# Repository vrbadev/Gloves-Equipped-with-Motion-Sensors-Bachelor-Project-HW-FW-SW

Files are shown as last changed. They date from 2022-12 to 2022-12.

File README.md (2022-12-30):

# Gloves Equipped with Motion Sensors (HW & FW & SW)
 This project was created as a part of my bachelor thesis at the Czech Technical University. It contains complete hardware, firmware and software designs for smart Bluetooth gloves equipped with 15 6-DOF IMU sensors.

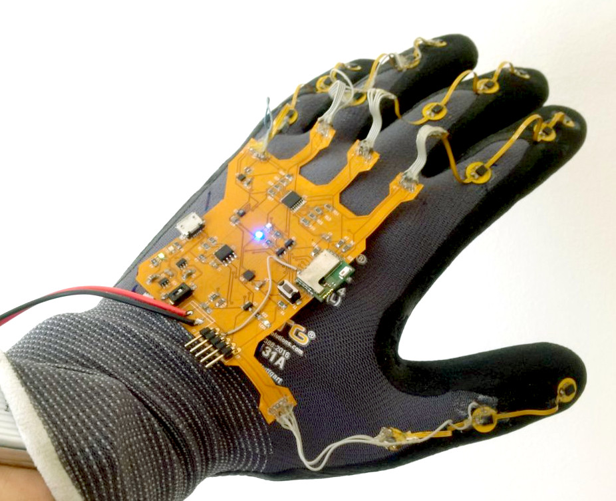
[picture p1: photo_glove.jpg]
Photo of the assembled glove


## About the Bachelor Thesis (Abstract)

This bachelor thesis focuses on the development of gloves equipped with motion sensors. The result of this work is supposed to be a functional device including 3D visualisation of measured bending of all fingers, so hand gestures can be determined. First of all, the theory of Bluetooth Low Energy devices is presented.The next chapter contains an explanation of hardware design details. Then the software implementation for the programmable BLE module is presented. Explanation of the theory of quaternion representation of the rotation and orientation in space for Madgwick's AHRS algorithm can be also found in this work. Python language has been chosen for implementing the visualisation. The thesis is completed with achieved results and ideas for further development.

Full text (in Czech language) is available at: https://dspace.cvut.cz/handle/10467/87657?locale-attribute=en

## Repository Contents

* **Hardware folder** - Contains complete Autodesk EAGLE projects for all related PCBs, including PDF schematics and layout visualisations.
* **Gerber folder** - Contains GERBER production archives for all of the designed PCBs.
* **Firmware folder** - Contains complete Keil uVision project with the firmware for the STMicroelectronics BlueNRG-M2SA Bluetooth module.
* **Software folder** - Contains Python software used for processing of the IMU data and for the visualisation.

## 3D Visualisation Software

A screenshot of the Python visualiser and the static code analysis are shown below.

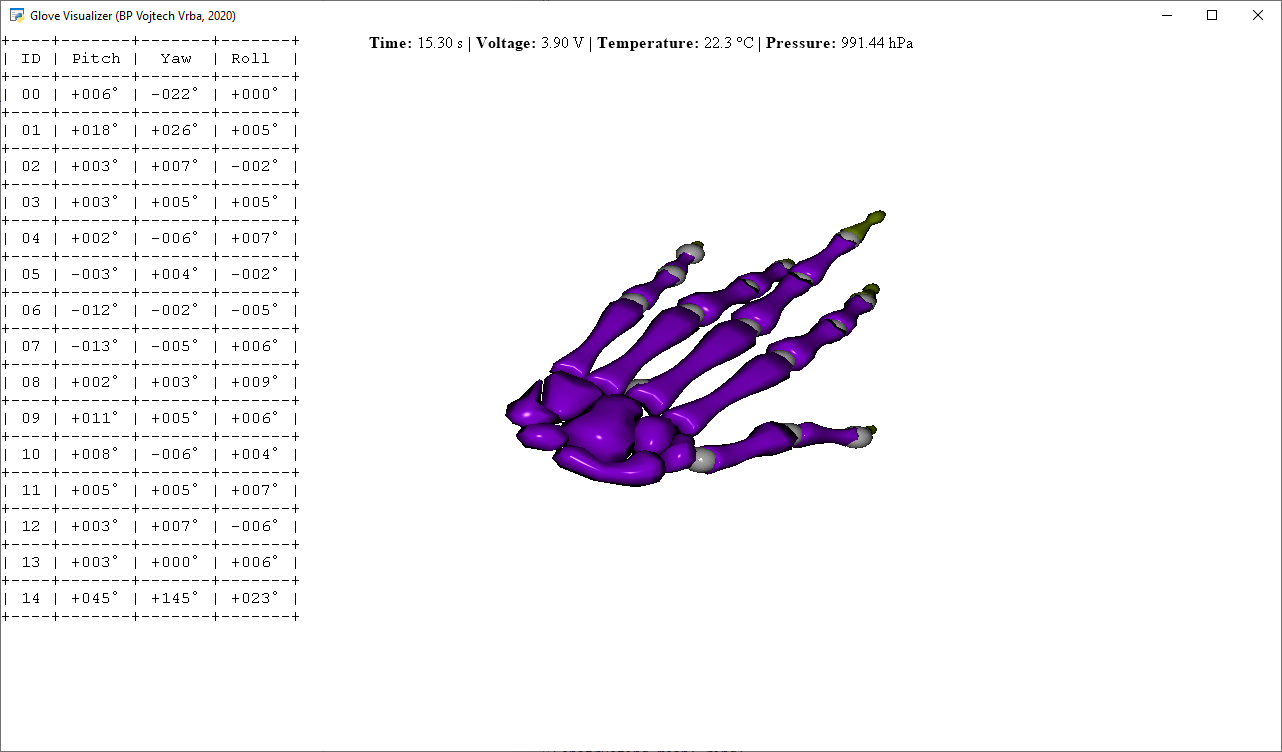
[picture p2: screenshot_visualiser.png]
Screenshot of the visualisation


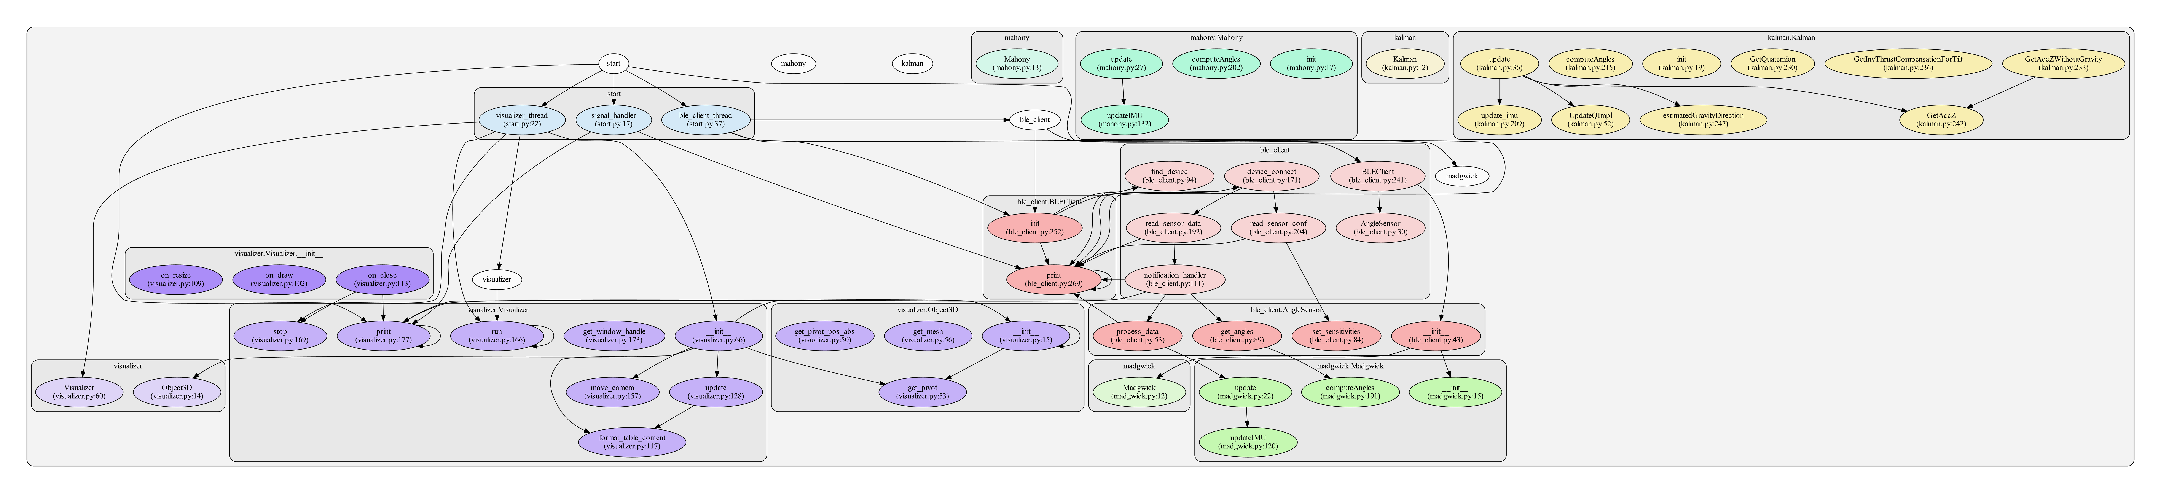
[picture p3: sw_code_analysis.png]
Static code analysis


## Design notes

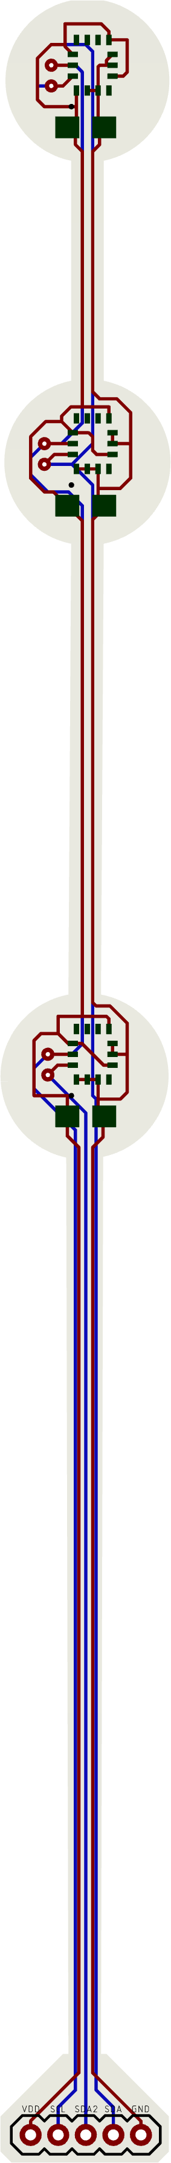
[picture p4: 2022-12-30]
Hardware/layout-little-finger.png

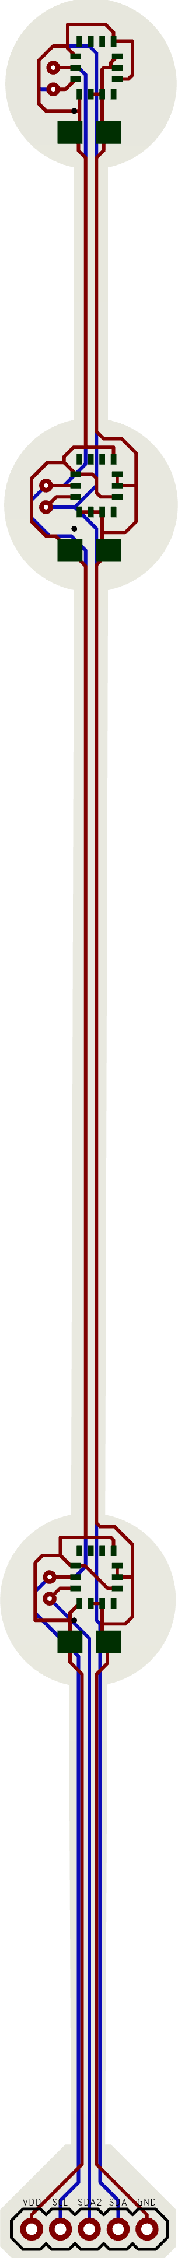
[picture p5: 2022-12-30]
Hardware/layout-index-finger.png

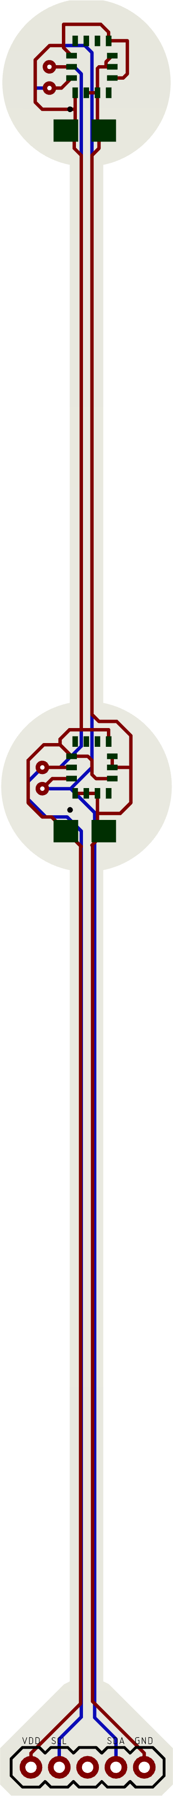
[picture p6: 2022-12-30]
Hardware/layout-thumb.png

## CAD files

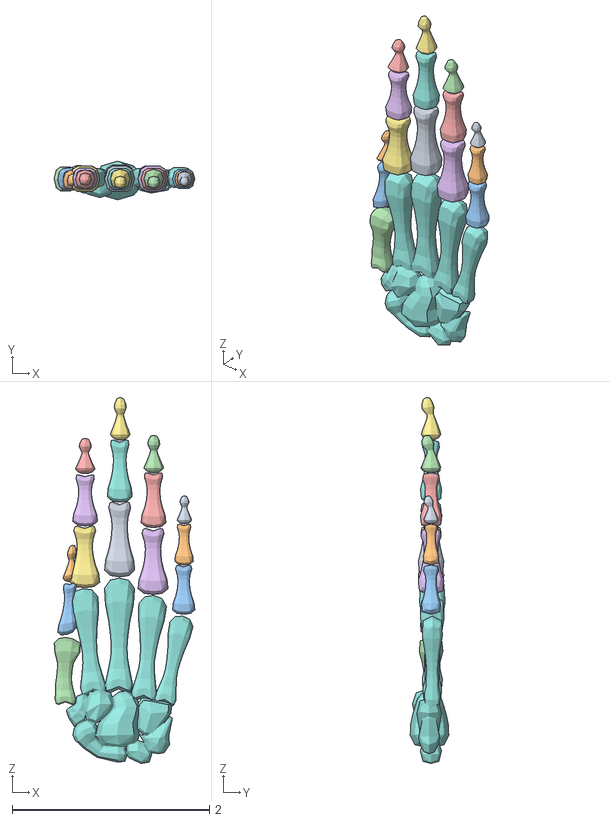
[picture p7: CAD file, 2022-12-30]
Software/Python/hand.obj
1.43 x 0.392 x 3.71
little3
little2
little1
ring3
ring2
ring1
middle3
middle2
middle1
thumb3
thumb2
thumb1
index3
index2
index1
hand

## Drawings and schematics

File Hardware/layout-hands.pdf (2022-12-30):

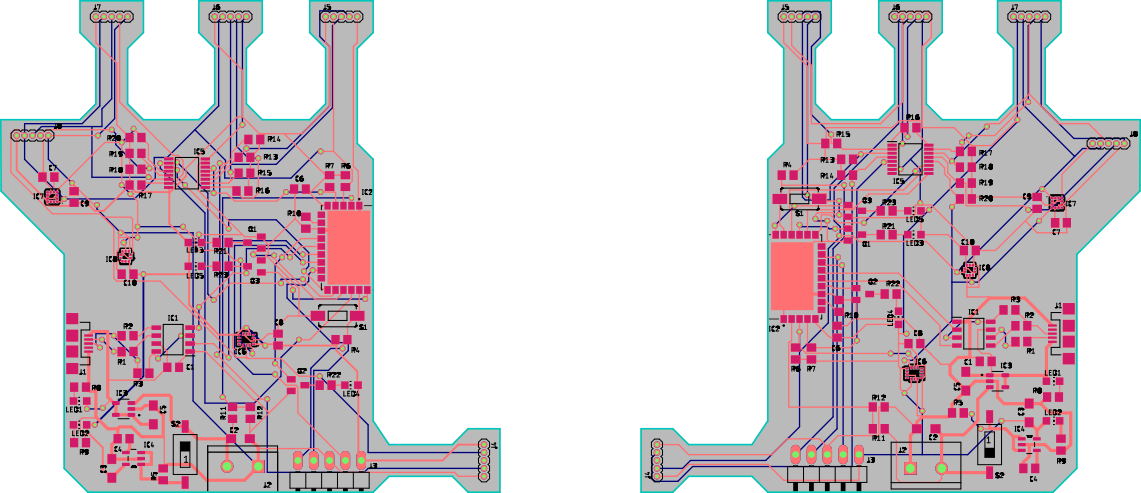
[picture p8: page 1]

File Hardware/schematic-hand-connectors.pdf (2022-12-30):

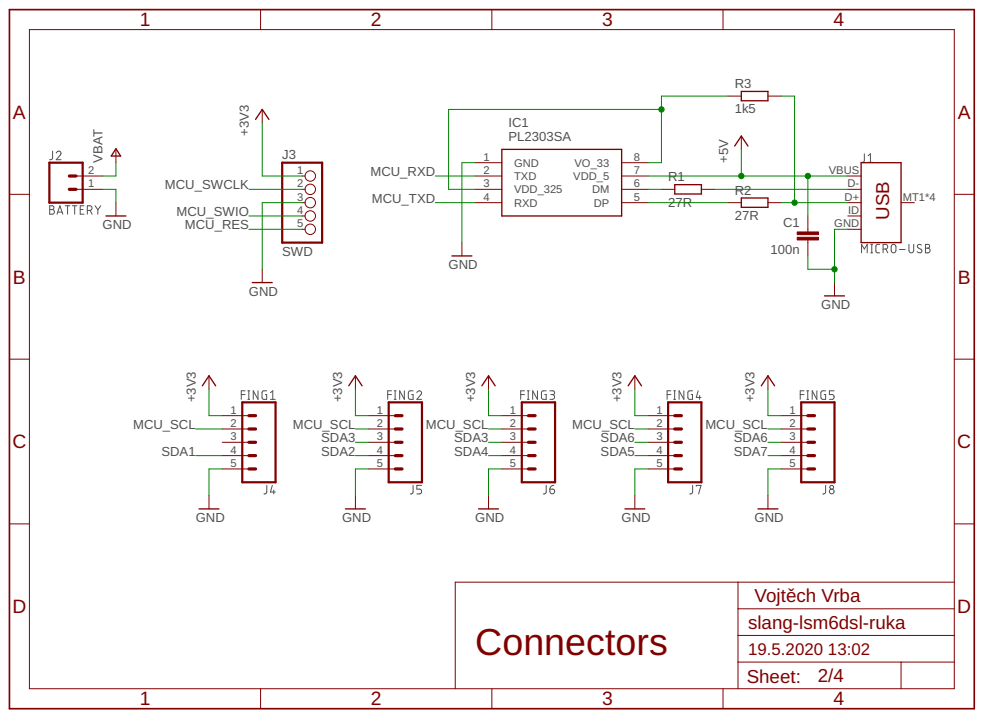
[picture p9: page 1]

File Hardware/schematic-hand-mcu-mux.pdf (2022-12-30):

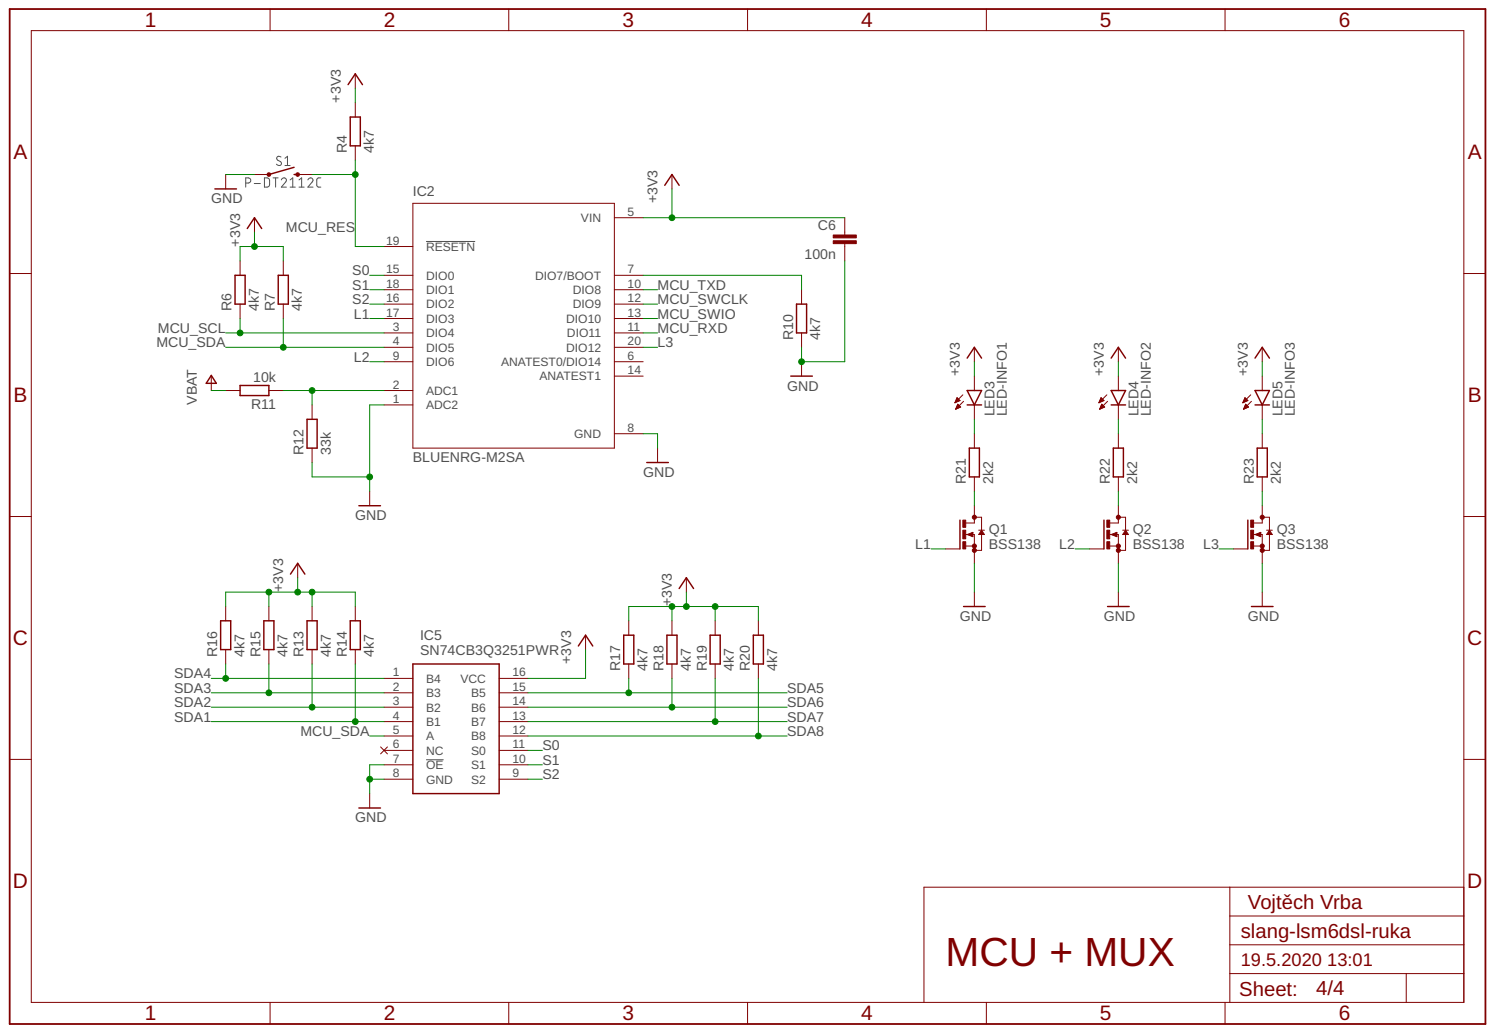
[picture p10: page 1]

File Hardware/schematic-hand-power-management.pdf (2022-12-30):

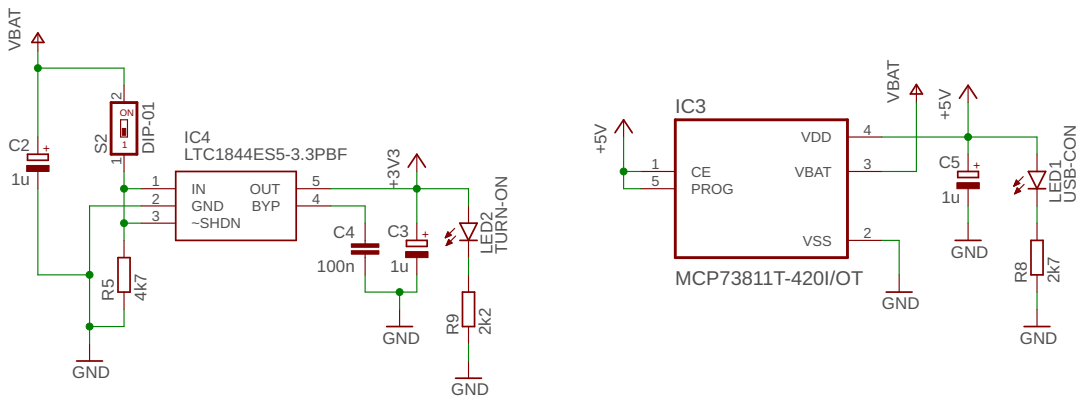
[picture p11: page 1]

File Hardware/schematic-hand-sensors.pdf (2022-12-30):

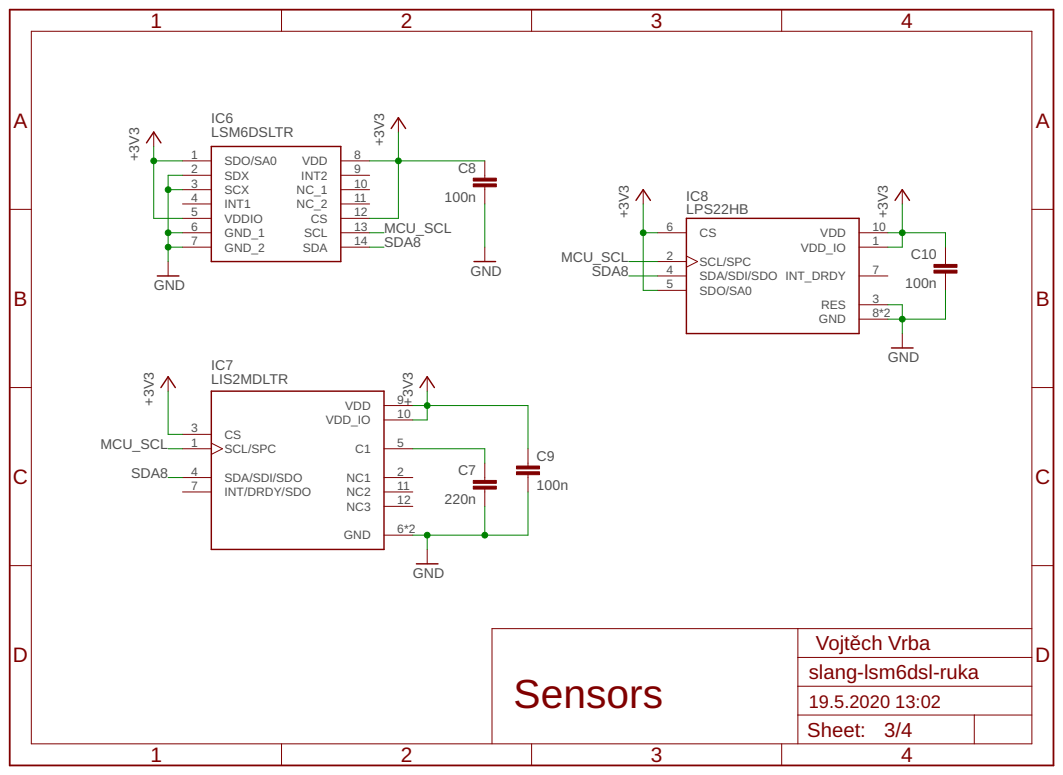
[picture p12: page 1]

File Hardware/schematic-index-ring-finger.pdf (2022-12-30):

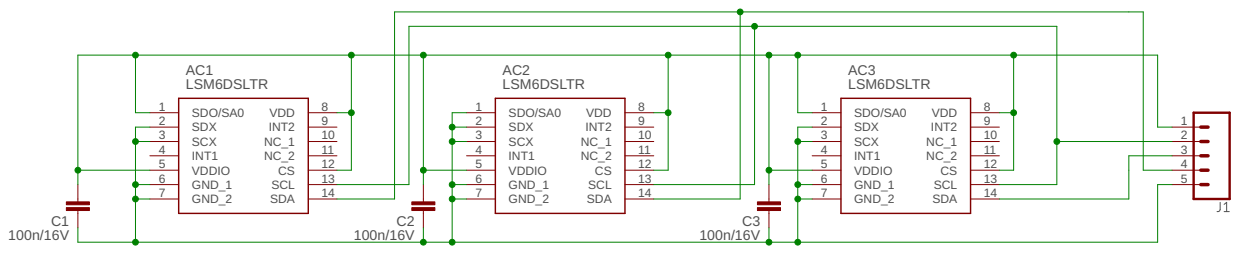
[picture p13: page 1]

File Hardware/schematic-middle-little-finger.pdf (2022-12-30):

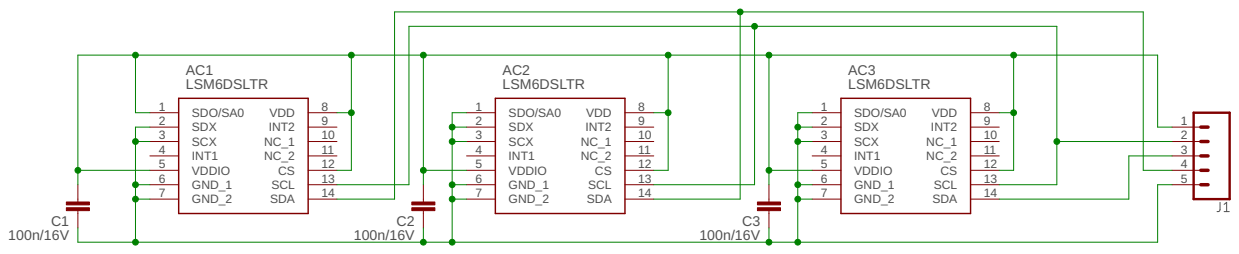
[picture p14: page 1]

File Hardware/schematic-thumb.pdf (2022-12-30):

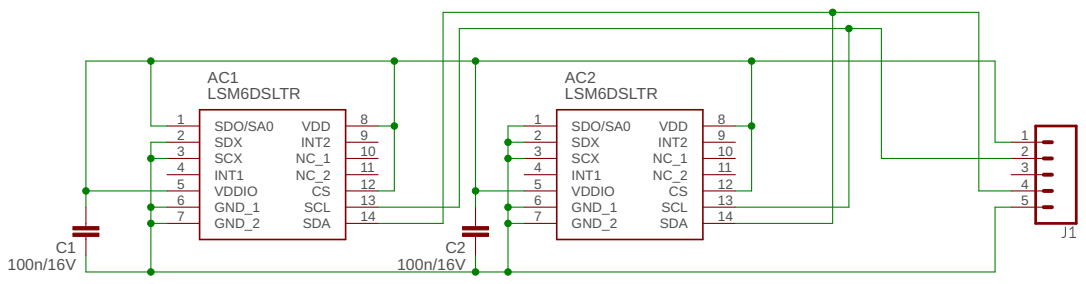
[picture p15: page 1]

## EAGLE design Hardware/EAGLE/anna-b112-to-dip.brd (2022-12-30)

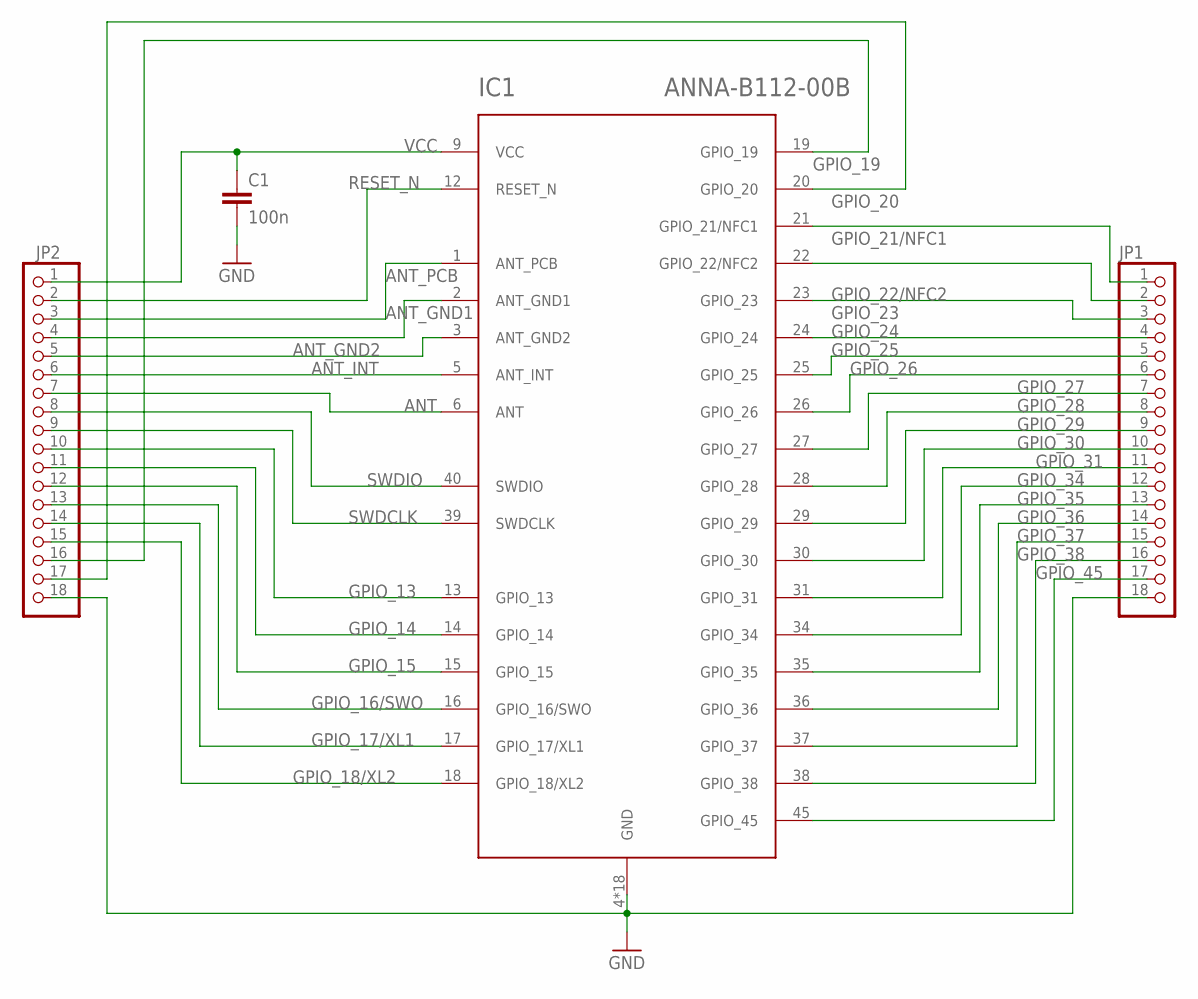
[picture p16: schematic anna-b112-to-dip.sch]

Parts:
C1: 100n; C0805
IC1: ANNA-B112-00B; ANNA-B112
JP1, JP2: PINHD-1X18; 1X18

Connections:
ANT: IC1.6 (ANT), JP2.7
ANT_GND1: IC1.2 (ANT_GND1), JP2.4
ANT_GND2: IC1.3 (ANT_GND2), JP2.5
ANT_INT: IC1.5 (ANT_INT), JP2.6
ANT_PCB: IC1.1 (ANT_PCB), JP2.3
GND: C1.2, IC1.4 (GND), IC1.7 (GND), IC1.8 (GND), IC1.10 (GND), IC1.11 (GND), IC1.32 (GND), IC1.33 (GND), IC1.41 (GND), IC1.42 (GND), IC1.43 (GND), IC1.44 (GND), IC1.46 (GND), IC1.47 (GND), IC1.48 (GND), IC1.49 (GND), IC1.50 (GND), IC1.51 (GND), IC1.52 (GND), JP1.18, JP2.18
GPIO_13: IC1.13 (GPIO_13), JP2.10
GPIO_14: IC1.14 (GPIO_14), JP2.11
GPIO_15: IC1.15 (GPIO_15), JP2.12
GPIO_16/SWO: IC1.16 (GPIO_16/SWO), JP2.13
GPIO_17/XL1: IC1.17 (GPIO_17/XL1), JP2.14
GPIO_18/XL2: IC1.18 (GPIO_18/XL2), JP2.15
GPIO_19: IC1.19 (GPIO_19), JP2.16
GPIO_20: IC1.20 (GPIO_20), JP2.17
GPIO_21/NFC1: IC1.21 (GPIO_21/NFC1), JP1.1
GPIO_22/NFC2: IC1.22 (GPIO_22/NFC2), JP1.2
GPIO_23: IC1.23 (GPIO_23), JP1.3
GPIO_24: IC1.24 (GPIO_24), JP1.4
GPIO_25: IC1.25 (GPIO_25), JP1.5
GPIO_26: IC1.26 (GPIO_26), JP1.6
GPIO_27: IC1.27 (GPIO_27), JP1.7
GPIO_28: IC1.28 (GPIO_28), JP1.8
GPIO_29: IC1.29 (GPIO_29), JP1.9
GPIO_30: IC1.30 (GPIO_30), JP1.10
GPIO_31: IC1.31 (GPIO_31), JP1.11
GPIO_34: IC1.34 (GPIO_34), JP1.12
GPIO_35: IC1.35 (GPIO_35), JP1.13
GPIO_36: IC1.36 (GPIO_36), JP1.14
GPIO_37: IC1.37 (GPIO_37), JP1.15
GPIO_38: IC1.38 (GPIO_38), JP1.16
GPIO_45: IC1.45 (GPIO_45), JP1.17
RESET_N: IC1.12 (RESET_N), JP2.2
SWDCLK: IC1.39 (SWDCLK), JP2.9
SWDIO: IC1.40 (SWDIO), JP2.8
VCC: C1.1, IC1.9 (VCC), JP2.1

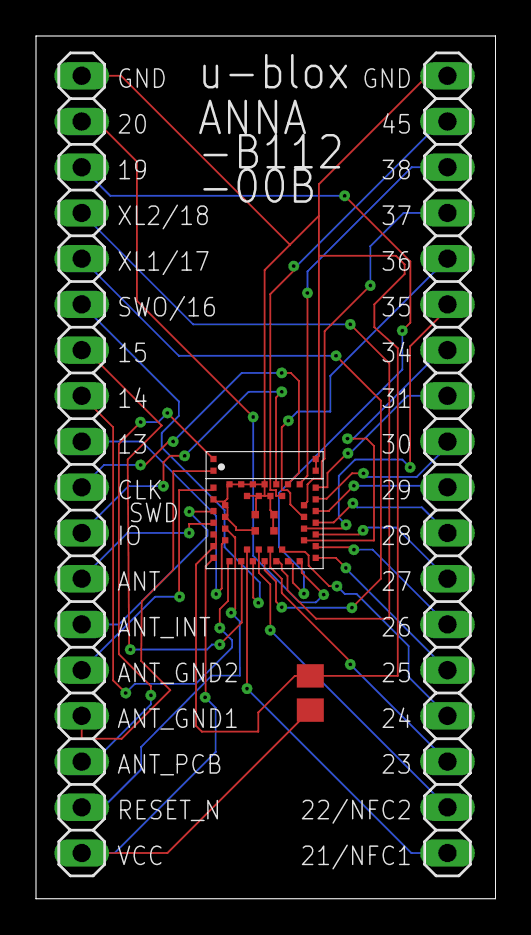
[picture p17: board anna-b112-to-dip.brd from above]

Board: 2 copper layers, 25.5 x 47.9 mm, 4 parts (0 on the bottom side), 35 nets.

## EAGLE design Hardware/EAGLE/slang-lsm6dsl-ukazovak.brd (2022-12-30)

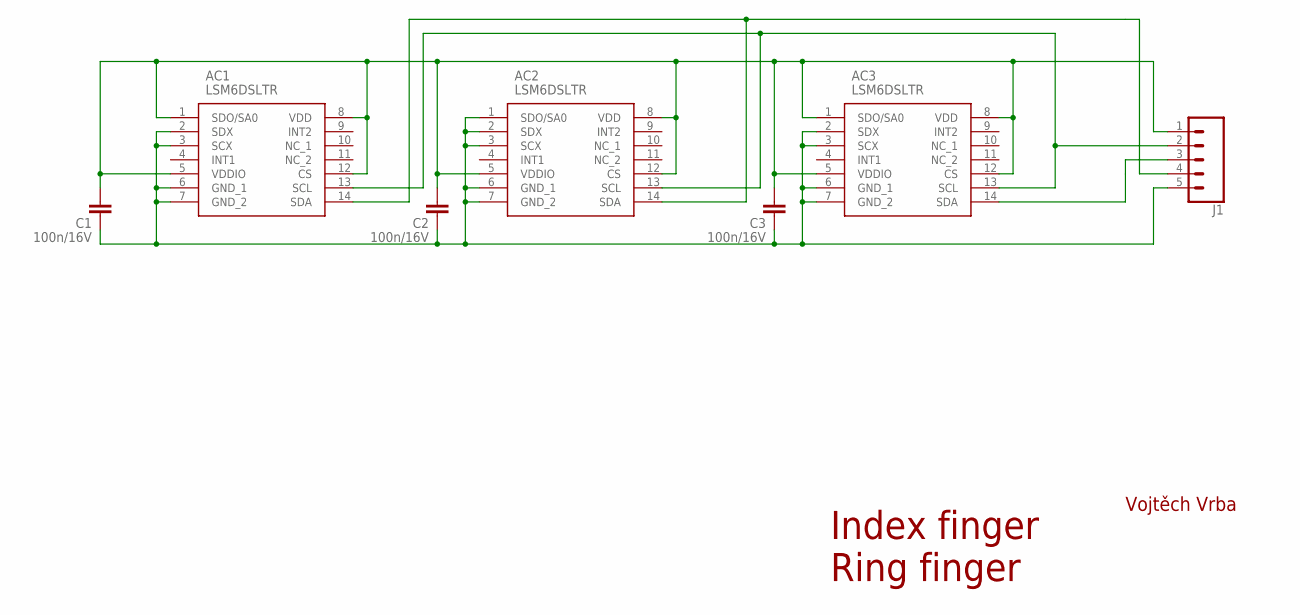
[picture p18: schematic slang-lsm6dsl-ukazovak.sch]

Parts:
AC1, AC2, AC3: LSM6DSLTR; LGA-14(2.5X3X0.86)
C1, C2, C3: 100n/16V; C0603
J1: CONN_051.27MM; 1X05_1.27MM

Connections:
GND: AC1.2 (SDX), AC1.3 (SCX), AC1.6 (GND_1), AC1.7 (GND_2), AC2.1 (SDO/SA0), AC2.2 (SDX), AC2.3 (SCX), AC2.6 (GND_1), AC2.7 (GND_2), AC3.2 (SDX), AC3.3 (SCX), AC3.6 (GND_1), AC3.7 (GND_2), C1.1, C2.1, C3.1, J1.5
SCL: AC1.13 (SCL), AC2.13 (SCL), AC3.13 (SCL), J1.2
SDA: AC1.14 (SDA), AC2.14 (SDA), J1.4
SDA2: AC3.14 (SDA), J1.3
VDD: AC1.1 (SDO/SA0), AC1.5 (VDDIO), AC1.8 (VDD), AC1.12 (CS), AC2.5 (VDDIO), AC2.8 (VDD), AC2.12 (CS), AC3.1 (SDO/SA0), AC3.5 (VDDIO), AC3.8 (VDD), AC3.12 (CS), C1.2, C2.2, C3.2, J1.1

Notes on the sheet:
Index finger Ring finger
Vojtěch Vrba

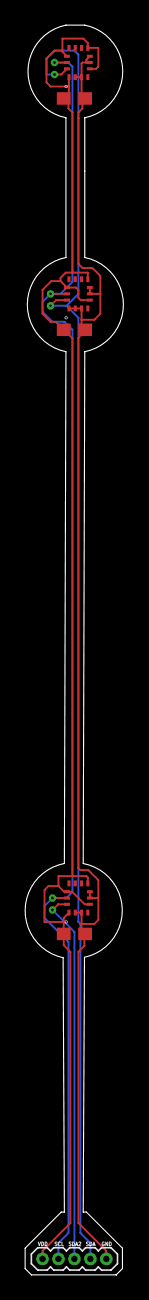
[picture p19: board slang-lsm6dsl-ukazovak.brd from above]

Board: 2 copper layers, 7.8 x 99.5 mm, 7 parts (0 on the bottom side), 5 nets.

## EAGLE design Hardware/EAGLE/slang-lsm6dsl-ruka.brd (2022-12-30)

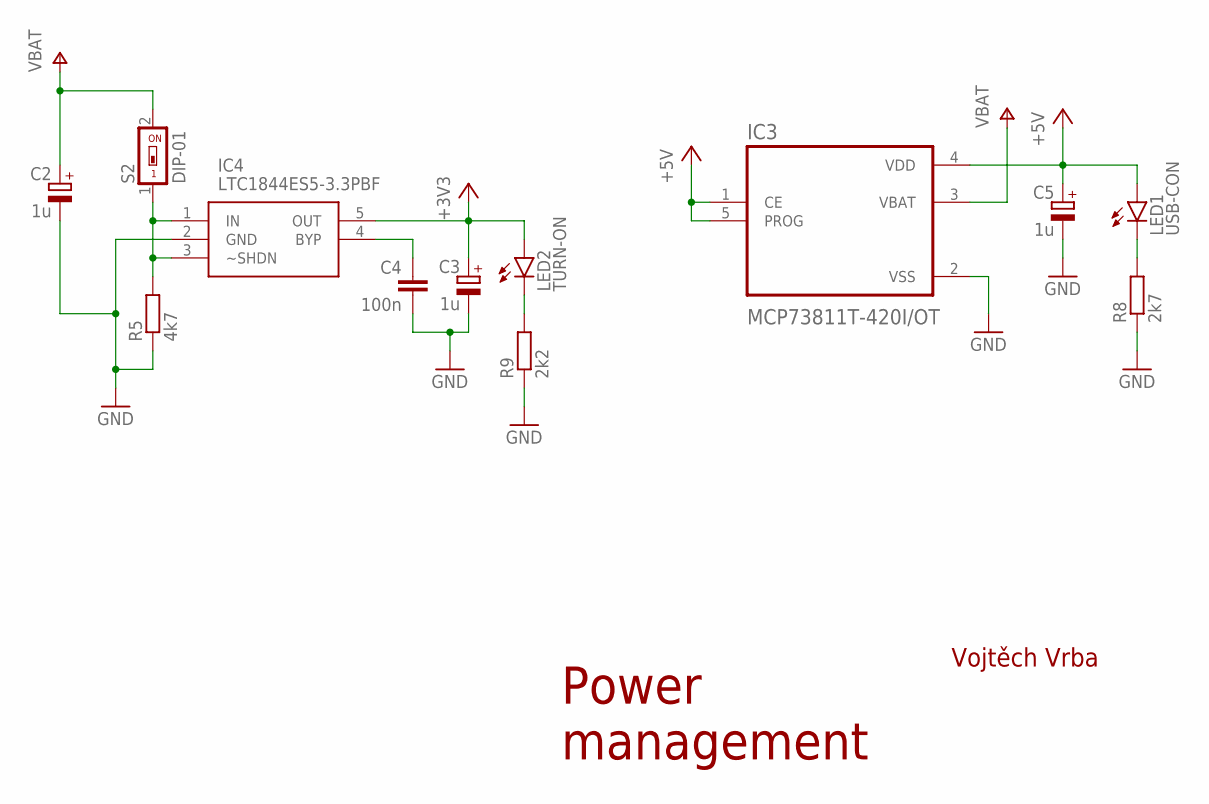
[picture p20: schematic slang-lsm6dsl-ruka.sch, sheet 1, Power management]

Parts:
C2, C3, C5: 1u; SMC_A
C4: 100n; C0805
IC3: MCP73811T-420I/OT; SOT95P280X145-5N
IC4: LTC1844ES5-3.3PBF; SOT95P280X100-5N
LED1: USB-CON; CHIP-LED0805
LED2: TURN-ON; CHIP-LED0805
R5: 4k7; R0805
R8: 2k7; R0805
R9: 2k2; R0805
S2: DIP-01; SMS-001

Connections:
+3V3: C3.+, IC4.5 (OUT), LED2.A; also elsewhere on the board
+5V: C5.+, IC3.1 (CE), IC3.4 (VDD), IC3.5 (PROG), LED1.A; also elsewhere on the board
GND: C2.-, C3.-, C4.2, C5.-, IC3.2 (VSS), IC4.2 (GND), R5.1, R8.1, R9.1; also elsewhere on the board
unnamed: LED1.C, R8.2
unnamed: C4.1, IC4.4 (BYP)
unnamed: IC4.1 (IN), IC4.3 (~SHDN), R5.2, S2.1
unnamed: LED2.C, R9.2
V+: C2.+, IC3.3 (VBAT), S2.2; also elsewhere on the board

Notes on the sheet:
Vojtěch Vrba
Power management

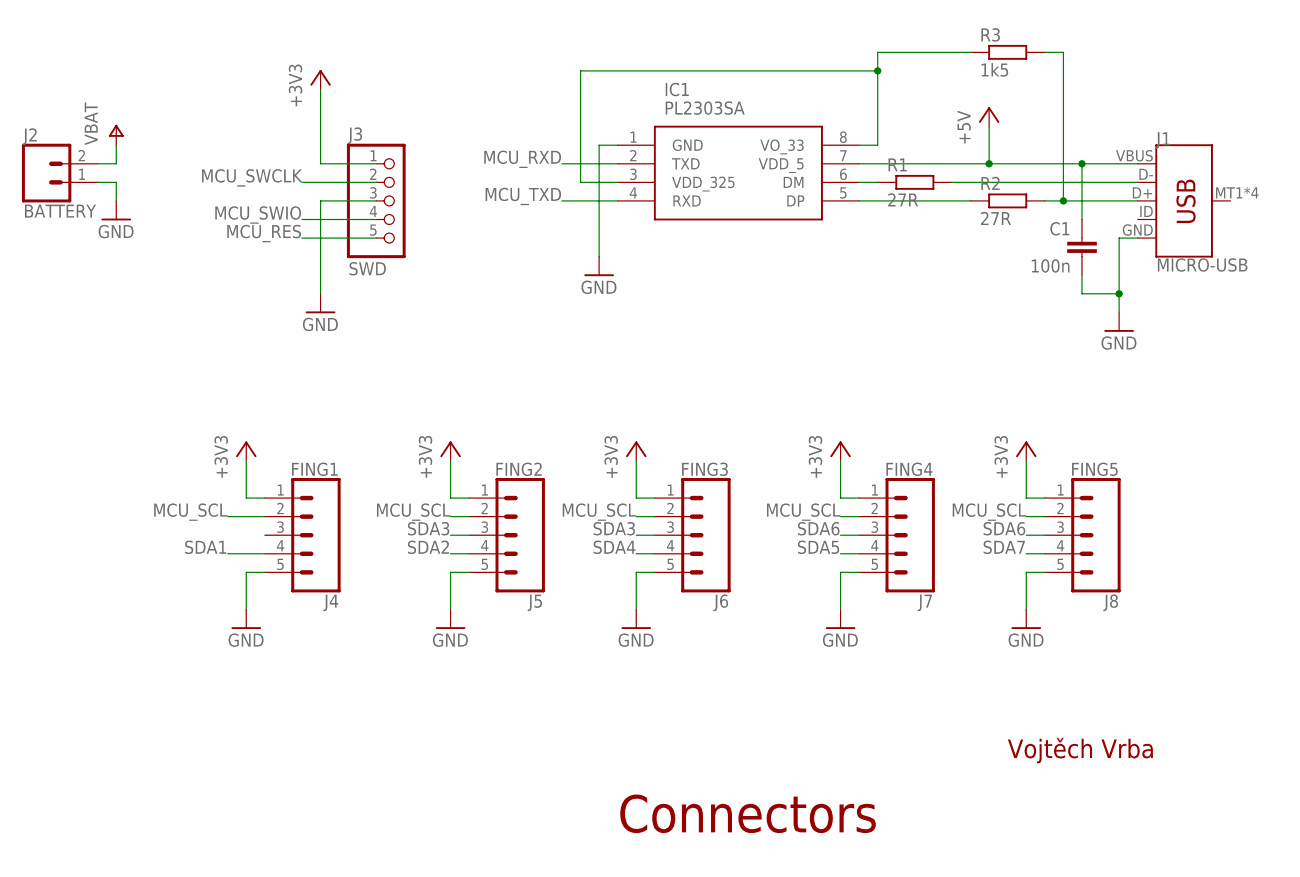
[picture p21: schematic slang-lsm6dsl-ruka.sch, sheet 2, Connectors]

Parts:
C1: 100n; C0805
IC1: PL2303SA; SOIC127P600X170-8N
J1: MICRO-USB; USB-MICROB
J2: BATTERY; SCREWTERMINAL-5MM-2
J3: SWD; 1X05/90
J4: FING1; 1X05_1.27MM
J5: FING2; 1X05_1.27MM
J6: FING3; 1X05_1.27MM
J7: FING4; 1X05_1.27MM
J8: FING5; 1X05_1.27MM
R1, R2: 27R; R0805
R3: 1k5; R0805

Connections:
+3V3: J3.1, J4.1, J5.1, J6.1, J7.1, J8.1; also elsewhere on the board
+5V: C1.1, IC1.7 (VDD_5), J1.VBUS; also elsewhere on the board
GND: C1.2, IC1.1 (GND), J1.GND, J2.1, J3.3, J4.5, J5.5, J6.5, J7.5, J8.5; also elsewhere on the board
MCU_RES: J3.5; also elsewhere on the board
MCU_RXD: IC1.2 (TXD); also elsewhere on the board
MCU_SCL: J4.2, J5.2, J6.2, J7.2, J8.2; also elsewhere on the board
MCU_SWCLK: J3.2; also elsewhere on the board
MCU_SWIO: J3.4; also elsewhere on the board
MCU_TXD: IC1.4 (RXD); also elsewhere on the board
unnamed: IC1.6 (DM), R1.1
unnamed: J1.D-, R1.2
unnamed: J1.D+, R2.2, R3.2
unnamed: IC1.5 (DP), R2.1
unnamed: IC1.3 (VDD_325), IC1.8 (VO_33), R3.1
SDA1: J4.4; also elsewhere on the board
SDA2: J5.4; also elsewhere on the board
SDA3: J5.3, J6.3; also elsewhere on the board
SDA4: J6.4; also elsewhere on the board
SDA5: J7.4; also elsewhere on the board
SDA6: J7.3, J8.3; also elsewhere on the board
SDA7: J8.4; also elsewhere on the board
V+: J2.2; also elsewhere on the board

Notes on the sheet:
Connectors
Vojtěch Vrba

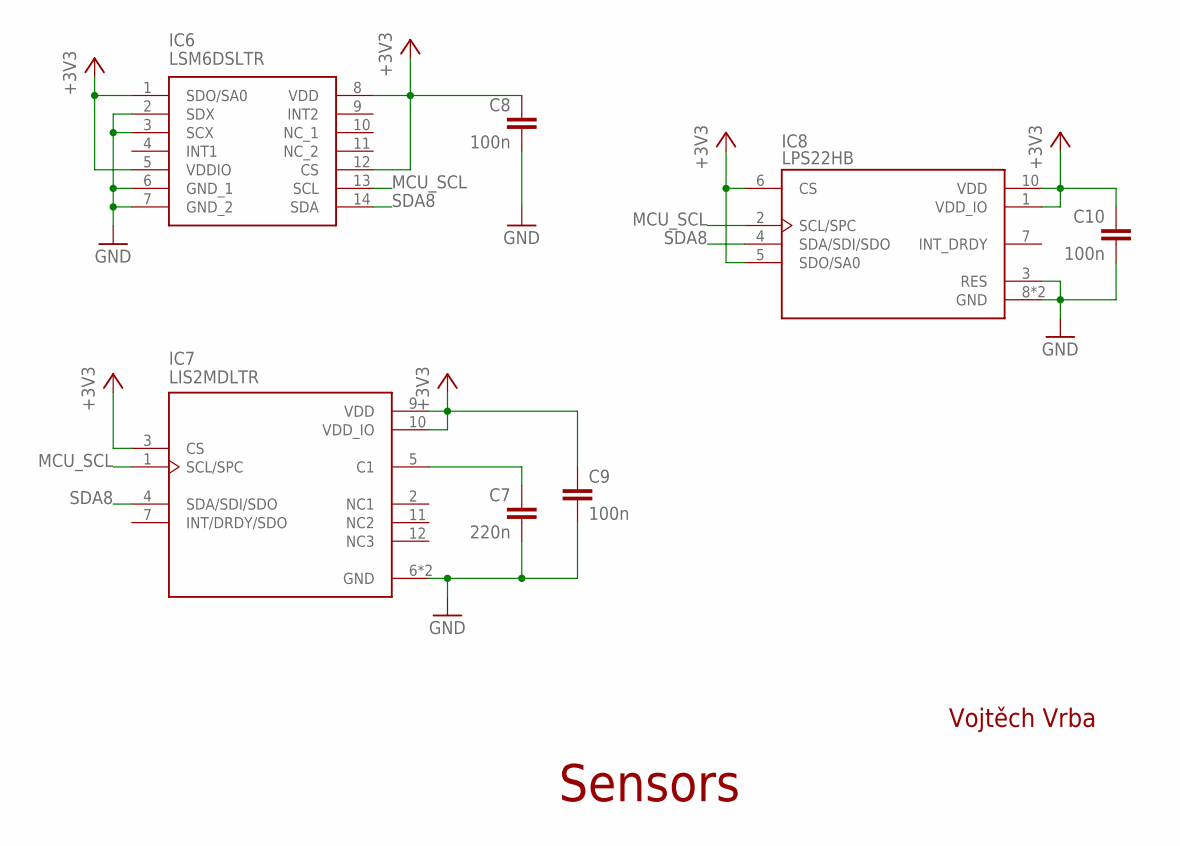
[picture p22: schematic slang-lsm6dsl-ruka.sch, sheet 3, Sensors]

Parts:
C7: 220n; C0805
C8, C9, C10: 100n; C0805
IC6: LSM6DSLTR; LGA-14(2.5X3X0.86)
IC7: LIS2MDLTR; PQFN50P200X200X70-12N
IC8: LPS22HB; LGA10R50P2X3_200X200X80

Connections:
+3V3: C8.1, C9.1, C10.1, IC6.1 (SDO/SA0), IC6.5 (VDDIO), IC6.8 (VDD), IC6.12 (CS), IC7.3 (CS), IC7.9 (VDD), IC7.10 (VDD_IO), IC8.1 (VDD_IO), IC8.5 (SDO/SA0), IC8.6 (CS), IC8.10 (VDD); also elsewhere on the board
GND: C7.2, C8.2, C9.2, C10.2, IC6.2 (SDX), IC6.3 (SCX), IC6.6 (GND_1), IC6.7 (GND_2), IC7.6 (GND), IC7.8 (GND), IC8.3 (RES), IC8.8 (GND), IC8.9 (GND); also elsewhere on the board
MCU_SCL: IC6.13 (SCL), IC7.1 (SCL/SPC), IC8.2 (SCL/SPC); also elsewhere on the board
unnamed: C7.1, IC7.5 (C1)
SDA8: IC6.14 (SDA), IC7.4 (SDA/SDI/SDO), IC8.4 (SDA/SDI/SDO); also elsewhere on the board

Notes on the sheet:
Vojtěch Vrba
Sensors

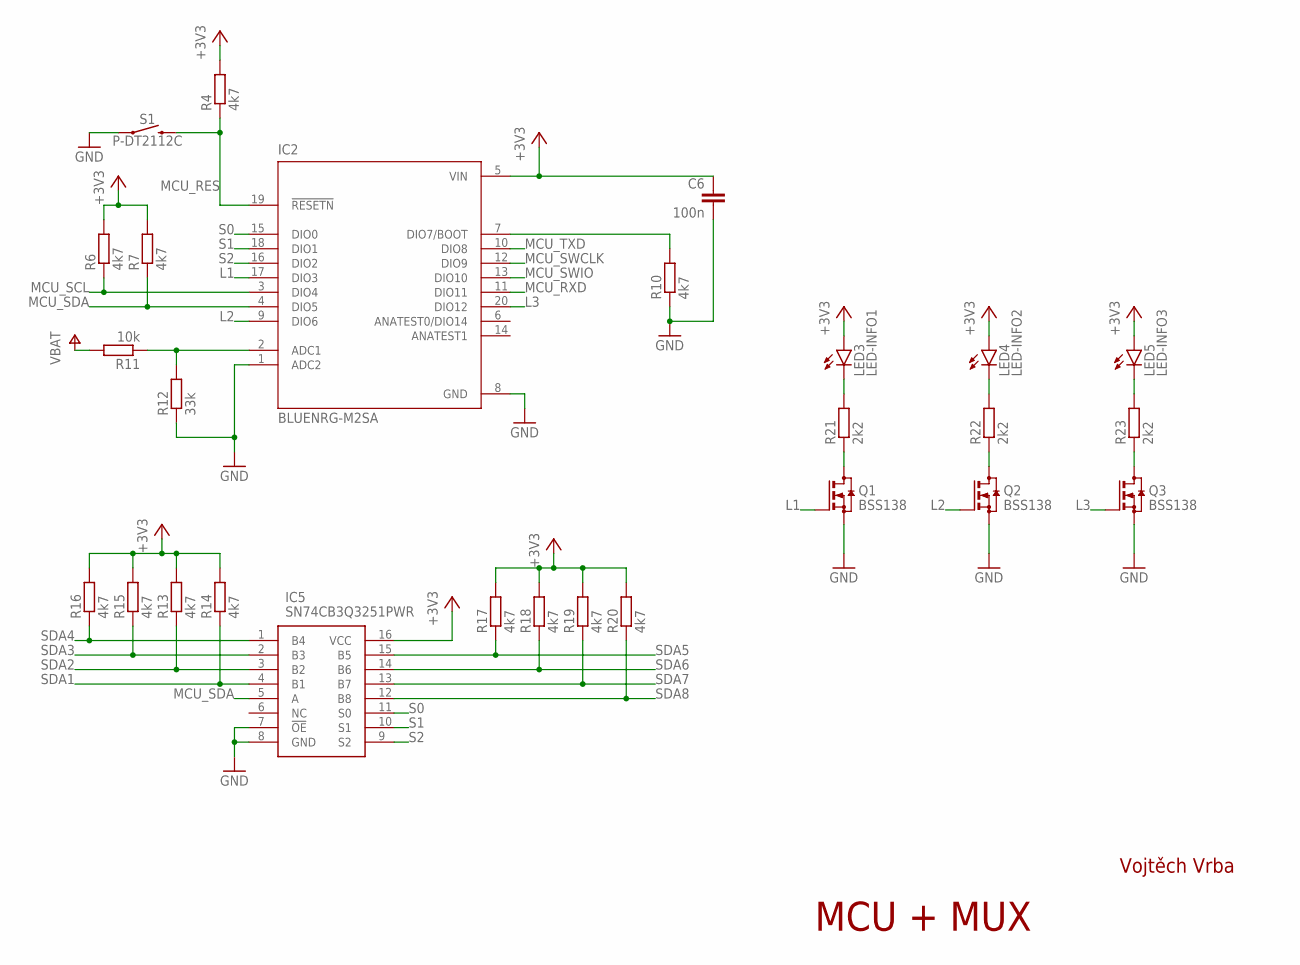
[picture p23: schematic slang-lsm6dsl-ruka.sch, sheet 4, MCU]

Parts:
C6: 100n; C0805
IC2: BLUENRG-M2SA; XCVR_BLUENRG-M2SA
IC5: SN74CB3Q3251PWR; SOP65P640X120-16N
LED3: LED-INFO1; CHIP-LED0805
LED4: LED-INFO2; CHIP-LED0805
LED5: LED-INFO3; CHIP-LED0805
Q1, Q2, Q3: BSS138; SOT23
R4, R6, R7, R10, R13, R14, R15, R16, R17, R18, R19, R20: 4k7; R0805
R11: 10k; R0805
R12: 33k; R0805
R21, R22, R23: 2k2; R0805
S1: P-DT2112C; TACTILE_SWITCH_SMD_6.0X3.5MM

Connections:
+3V3: C6.1, IC2.5 (VIN), IC5.16 (VCC), LED3.A, LED4.A, LED5.A, R4.2, R6.2, R7.2, R13.2, R14.2, R15.2, R16.2, R17.2, R18.2, R19.2, R20.2; also elsewhere on the board
GND: C6.2, IC2.1 (ADC2), IC2.8 (GND), IC5.7 (!OE), IC5.8 (GND), Q1.2 (S), Q2.2 (S), Q3.2 (S), R10.1, R12.1, S1.1; also elsewhere on the board
L1: IC2.17 (DIO3), Q1.1 (G)
L2: IC2.9 (DIO6), Q2.1 (G)
L3: IC2.20 (DIO12), Q3.1 (G)
MCU_RES: IC2.19 (!RESETN), R4.1, S1.2; also elsewhere on the board
MCU_RXD: IC2.11 (DIO11); also elsewhere on the board
MCU_SCL: IC2.3 (DIO4), R6.1; also elsewhere on the board
MCU_SDA: IC2.4 (DIO5), IC5.5 (A), R7.1
MCU_SWCLK: IC2.12 (DIO9); also elsewhere on the board
MCU_SWIO: IC2.13 (DIO10); also elsewhere on the board
MCU_TXD: IC2.10 (DIO8); also elsewhere on the board
unnamed: IC2.7 (DIO7/BOOT), R10.2
unnamed: IC2.2 (ADC1), R11.1, R12.2
unnamed: LED3.C, R21.2
unnamed: Q1.3 (D), R21.1
unnamed: LED4.C, R22.2
unnamed: Q2.3 (D), R22.1
unnamed: LED5.C, R23.2
unnamed: Q3.3 (D), R23.1
S0: IC2.15 (DIO0), IC5.11 (S0)
S1: IC2.18 (DIO1), IC5.10 (S1)
S2: IC2.16 (DIO2), IC5.9 (S2)
SDA1: IC5.4 (B1), R14.1; also elsewhere on the board
SDA2: IC5.3 (B2), R13.1; also elsewhere on the board
SDA3: IC5.2 (B3), R15.1; also elsewhere on the board
SDA4: IC5.1 (B4), R16.1; also elsewhere on the board
SDA5: IC5.15 (B5), R17.1; also elsewhere on the board
SDA6: IC5.14 (B6), R18.1; also elsewhere on the board
SDA7: IC5.13 (B7), R19.1; also elsewhere on the board
SDA8: IC5.12 (B8), R20.1; also elsewhere on the board
V+: R11.2; also elsewhere on the board

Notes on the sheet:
Vojtěch Vrba
MCU + MUX

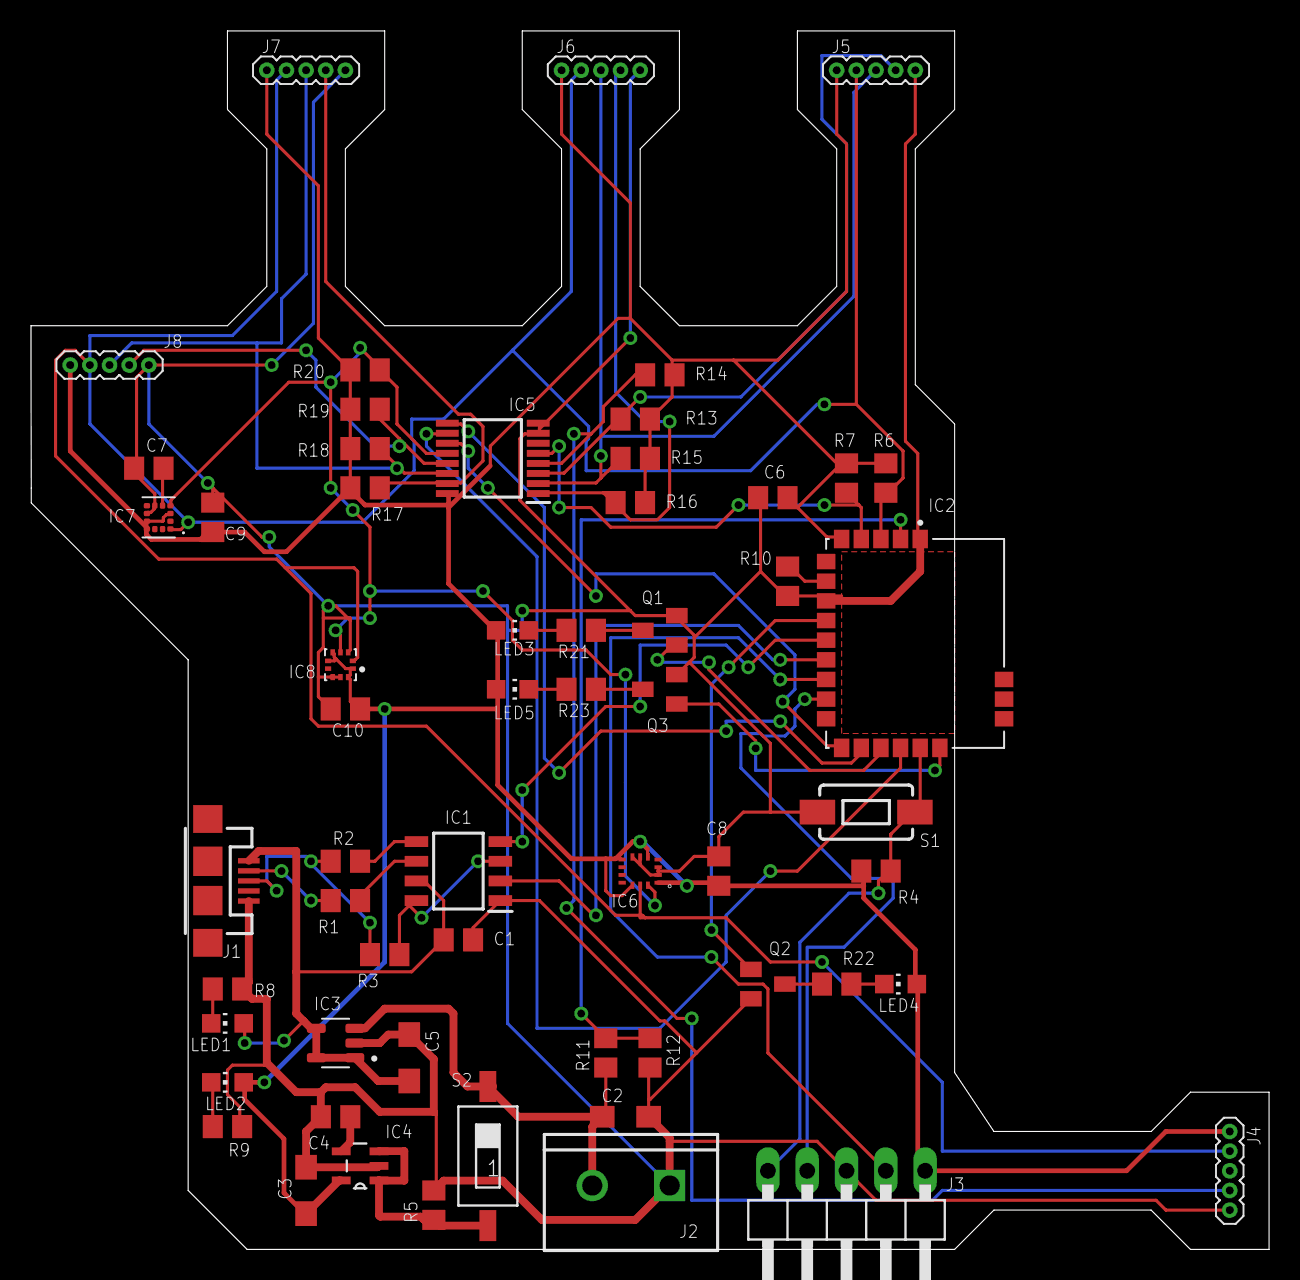
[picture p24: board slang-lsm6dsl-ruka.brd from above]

Board: 2 copper layers, 80.0 x 78.7 mm, 59 parts (0 on the bottom side), 43 nets.

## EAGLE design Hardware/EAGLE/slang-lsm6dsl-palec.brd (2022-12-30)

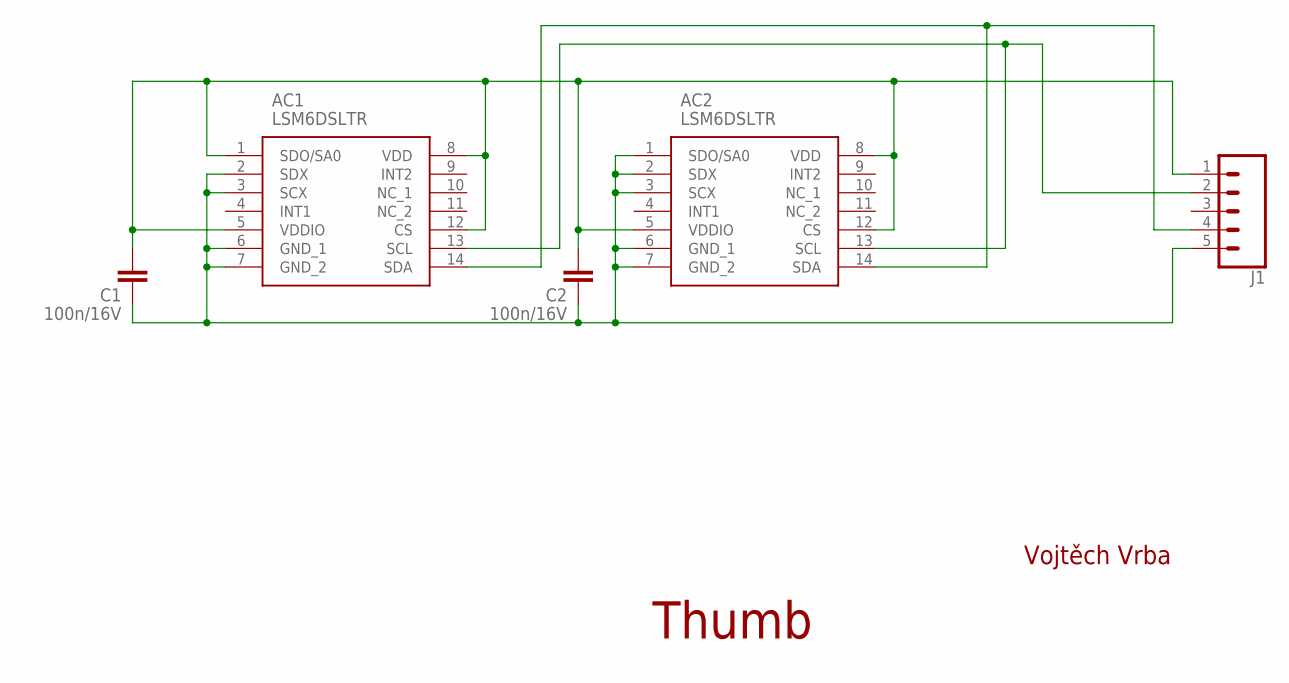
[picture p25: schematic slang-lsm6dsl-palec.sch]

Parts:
AC1, AC2: LSM6DSLTR; LGA-14(2.5X3X0.86)
C1, C2: 100n/16V; C0603
J1: CONN_051.27MM; 1X05_1.27MM

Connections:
GND: AC1.2 (SDX), AC1.3 (SCX), AC1.6 (GND_1), AC1.7 (GND_2), AC2.1 (SDO/SA0), AC2.2 (SDX), AC2.3 (SCX), AC2.6 (GND_1), AC2.7 (GND_2), C1.1, C2.1, J1.5
SCL: AC1.13 (SCL), AC2.13 (SCL), J1.2
SDA: AC1.14 (SDA), AC2.14 (SDA), J1.4
VDD: AC1.1 (SDO/SA0), AC1.5 (VDDIO), AC1.8 (VDD), AC1.12 (CS), AC2.5 (VDDIO), AC2.8 (VDD), AC2.12 (CS), C1.2, C2.2, J1.1

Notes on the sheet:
Thumb
Vojtěch Vrba

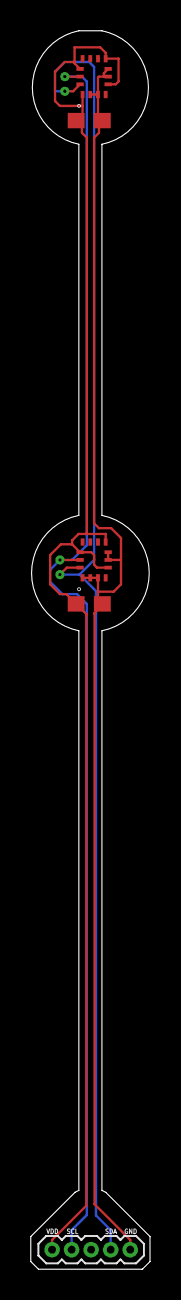
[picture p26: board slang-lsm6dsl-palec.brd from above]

Board: 2 copper layers, 7.8 x 80.5 mm, 5 parts (0 on the bottom side), 4 nets.

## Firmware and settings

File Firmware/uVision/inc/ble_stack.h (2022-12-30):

#pragma once

#ifndef BLE_STACK_H__
#define BLE_STACK_H__

#include "stack_user_cfg.h"
#include "ble_const.h"
#include "bluenrg1_stack.h"

/* Default number of link */
#define MIN_NUM_LINK            1
/* Default number of GAP and GATT services */
#define DEFAULT_NUM_GATT_SERVICES   2
/* Default number of GAP and GATT attributes */
#define DEFAULT_NUM_GATT_ATTRIBUTES 9


/* Number of services requests */
#define NUM_APP_GATT_SERVICES 1

/* Number of attributes requests */
#define NUM_APP_GATT_ATTRIBUTES 15

#define SENSOR_MAX_ATT_SIZE (247) 

/* 
 * Number of links needed for the BLE app.
 * Only 1 by default (MIN_NUM_LINK).
 * --------------------------
 * Maximum number of simultaneous connections that the device will support. 
 * Valid values are from 1 to 8 (NUM_LINKS used in the calculation of TOTAL_BUFFER_SIZE).
 */
#define NUM_LINKS               (MIN_NUM_LINK)

/* 
 * Number of GATT attributes needed for the BLE app. 
 * ----------------------------
 * Maximum number of Attributes (i.e. the number of characteristic + the number 
 * of characteristic values + the number of descriptors, excluding the services) 
 * that can be stored in the GATT database. Note that certain characteristics and 
 * relative descriptors are added automatically during device initialization so 
 * this parameters should be 9 plus the number of user Attributes 
 * (NUM_GATT_ATTRIBUTES used in the calculation of TOTAL_BUFFER_SIZE)
 */
#define NUM_GATT_ATTRIBUTES     (DEFAULT_NUM_GATT_ATTRIBUTES + NUM_APP_GATT_ATTRIBUTES)

/* 
 * Number of GATT services needed for the BLE app. 
 * -----------------------------
 * Maximum number of Services that can be stored in the GATT database. Note that 
 * the GAP and GATT services are automatically added so this parameter should be 
 * 2 plus the number of user services (NUM_GATT_SERVICES used in the calculation 
 * of TOTAL_BUFFER_SIZE)
 */
#define NUM_GATT_SERVICES       (DEFAULT_NUM_GATT_SERVICES + NUM_APP_GATT_SERVICES)

/* 
 * Array size for the attribute value 
 * ----------------------------
 * Size of the storage area for Attribute values (ATT_VALUE_ARRAY_SIZE used 
 * in the calculation of TOTAL_BUFFER_SIZE).
 * This value depends on the number of attributes used by application. 
 * In particular the sum of the following quantities (in octets) 
 * should be made for each attribute:
 *   - attribute value length
 *   - 5, if UUID is 16 bit; 19, if UUID is 128 bit
 *   - 2, if server configuration descriptor is used
 *   - 2*numOfLinks, if client configuration descriptor is used
 *   - 2, if extended properties is used
 *
 * The total amount of memory needed is the sum of the above quantities for each attribute.
 */
#define ATT_VALUE_ARRAY_SIZE    (1600) 

/* 
 * Flash security database size
 * ----------------------------
 * Size of the database used to store security information for bonded devices 
 * (FLASH_SEC_DB_SIZE used in the calculation of TOTAL_FLASH_BUFFER_SIZE). 
 * Current SUPPORTED VALUE is 1024
*/
#define FLASH_SEC_DB_SIZE       (0x400)

/* 
 * Flash server database size
 * --------------------------
 * Size of the database used for service change notification for bonded devices 
 * (FLASH_SERVER_DB_SIZE used in the calculation of TOTAL_FLASH_BUFFER_SIZE). 
 * Current SUPPORTED VALUE is 1024
 */
#define FLASH_SERVER_DB_SIZE    (0x400)

/* Set supported max value for ATT_MTU enabled by the application. Allowed values in range: [23:158] [New parameter added on BLE stack v2.x] */
#define MAX_ATT_MTU             247

/* Set supported max value for attribute size: it is the biggest attribute size enabled by the application */
#define MAX_ATT_SIZE            (SENSOR_MAX_ATT_SIZE)  

/* 
 * Prepare Write List size in terms of number of packet with ATT_MTU bytes
 * ---------------------------------
 * Set the minumum number of prepare write requests needed for a long write 
 * procedure for a characteristic with len > 20bytes: 
 * 
 * It returns 0 for characteristics with len <= 20bytes
 * 
 * NOTE: If prepare write requests are used for a characteristic (reliable write on multiple characteristics), then 
 * this value should be set to the number of prepare write needed by the application.
*/
#define PREPARE_WRITE_LIST_SIZE PREP_WRITE_X_ATT(MAX_ATT_SIZE) 

/* 
 * Additional number of memory blocks  to be added to the minimum 
 * -------------------------------------
 * 6 for reaching the max throughput: ~220kbps (same as BLE stack 1.x)
 */
#define OPT_MBLOCKS		(6) /*  */

/* 
 * Set the number of memory block for packet allocation 
*/
#define MBLOCKS_COUNT           (MBLOCKS_CALC(PREPARE_WRITE_LIST_SIZE, MAX_ATT_MTU, NUM_LINKS) + OPT_MBLOCKS)

/* 
 * RAM reserved to manage all the data stack according the number of links,
 * number of services, number of attributes and attribute value length
 * -----------------------------------
 * Start address of the RAM buffer for GATT database allocated according to 
 * TOTAL_BUFFER_SIZE (32bit aligned RAM area) - its return value is used to 
 * check the MACRO correctness.
*/
NO_INIT(uint32_t dyn_alloc_a[TOTAL_BUFFER_SIZE(NUM_LINKS,NUM_GATT_ATTRIBUTES,NUM_GATT_SERVICES,ATT_VALUE_ARRAY_SIZE,MBLOCKS_COUNT,CONTROLLER_DATA_LENGTH_EXTENSION_ENABLED)>>2]);

/* 
 * FLASH reserved to store all the security database information and
 * and the server database information.
 * ------------------------------------
 * Start address for the non-volatile memory area allocated according 
 * to TOTAL_FLASH_BUFFER_SIZE (Aligned to 2048 bytes flash sector boundary).
 */
NO_INIT_SECTION(uint32_t stacklib_flash_data[TOTAL_FLASH_BUFFER_SIZE(FLASH_SEC_DB_SIZE, FLASH_SERVER_DB_SIZE)>>2], ".noinit.stacklib_flash_data");

/* 
 * FLASH reserved to store: security root keys, static random address, public address 
 * ------------------------------------
 * stacklib_stored_device_id_data is address of the const device id data vector 
 * (56 bytes, 32bit aligned FLASH area, all elements must be initialized to 0xFF).
 */
NO_INIT_SECTION(uint8_t stacklib_stored_device_id_data[56], ".noinit.stacklib_stored_device_id_data");

// ****************************************
// HW STRUCTURE members
// ****************************************

/* Radio Config Hot Table */
extern uint8_t hot_table_radio_config[];

/* Maximum duration of the connection event */
#define MAX_CONN_EVENT_LENGTH 0xFFFFFFFF

/* Sleep clock accuracy */
#if (LS_SOURCE == LS_SOURCE_INTERNAL_RO)

  /* Sleep clock accuracy in Slave mode */
  #define SLAVE_SLEEP_CLOCK_ACCURACY 500

  /* Sleep clock accuracy in Master mode */
  #define MASTER_SLEEP_CLOCK_ACCURACY MASTER_SCA_500ppm

#else

  /* Sleep clock accuracy in Slave mode */
  #define SLAVE_SLEEP_CLOCK_ACCURACY 100

  /* Sleep clock accuracy in Master mode */
  #define MASTER_SLEEP_CLOCK_ACCURACY MASTER_SCA_100ppm

#endif

/* Low Speed Oscillator source */
#if (LS_SOURCE == LS_SOURCE_INTERNAL_RO)
  #define LOW_SPEED_SOURCE  1 // Internal RO
#else
  #define LOW_SPEED_SOURCE  0 // External 32 KHz
#endif

/* High Speed start up time */
#define HS_STARTUP_TIME 328 // 800 us

/* 
 * CREATE HW CONFIG STRUCTURE
 * Structure containing low level hardware configuration data for the device
*/
#define CONFIG_TABLE            \
{                               \
  (uint32_t*)hot_table_radio_config,          \
  MAX_CONN_EVENT_LENGTH,        \
  SLAVE_SLEEP_CLOCK_ACCURACY,   \
  MASTER_SLEEP_CLOCK_ACCURACY,  \
  LOW_SPEED_SOURCE,             \
  HS_STARTUP_TIME               \
}

// CREATE INIT STRUCUTRE
// This structure contains memory and low level hardware configuration data for the device

const BlueNRG_Stack_Initialization_t BlueNRG_Stack_Init_params = {
    (uint8_t*)stacklib_flash_data,
    FLASH_SEC_DB_SIZE,
    FLASH_SERVER_DB_SIZE,
    (uint8_t*)stacklib_stored_device_id_data,
    (uint8_t*)dyn_alloc_a,
    TOTAL_BUFFER_SIZE(NUM_LINKS,NUM_GATT_ATTRIBUTES,NUM_GATT_SERVICES,ATT_VALUE_ARRAY_SIZE,MBLOCKS_COUNT,CONTROLLER_DATA_LENGTH_EXTENSION_ENABLED),
    NUM_GATT_ATTRIBUTES,
    NUM_GATT_SERVICES,
    ATT_VALUE_ARRAY_SIZE,
    NUM_LINKS,
    0, /* extended_packet_length_enable - reserved for future use */
    PREPARE_WRITE_LIST_SIZE,
    MBLOCKS_COUNT,
    MAX_ATT_MTU,
    CONFIG_TABLE,
};

/** 
 * @brief Number of application services
 */
#define NUMBER_OF_APPLICATION_SERVICES (1)

/* Maximum number of attribute records that can be added to the first application service: acceleration service */
#define MAX_NUMBER_ATTRIBUTES_RECORDS_SERVICE_1 (7) 

/* Set the Application Service Max number of attributes records with init parameters coming from application *.config.h file */
uint8_t Services_Max_Attribute_Records[NUMBER_OF_APPLICATION_SERVICES] = {MAX_NUMBER_ATTRIBUTES_RECORDS_SERVICE_1};

#endif

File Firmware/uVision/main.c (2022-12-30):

/**************************************************************
File:         main.c
Application:  Smart gloves for gesture recognition
Date:         April 2020
Author:       Vojtech Vrba
              FEE CTU in Prague
              
Known bugs:   1) LED5 can't be connected to the pin DIO12 
                 (input-only) -> doesn't work
              2) BSS138 transistors for switching LEDs lack
                 pull-down resistors -> capacitance of traces
                 forces LEDs to turn on and off randomly
***************************************************************/

#include "BlueNRG_x_device.h"
#include "sleep.h"

#include "inc/delay.h"
#include "inc/uart.h"
#include "inc/adc.h"
#include "inc/i2c.h"
#include "inc/ble_app.h"
#include "inc/sensors.h"

/* Indication LEDs pins definition */
#define PIN_LED3 GPIO_Pin_3 // yellow
#define PIN_LED4 GPIO_Pin_6 // red
#define PIN_LED5 GPIO_Pin_12 // blue

/* MUX select pins definition */
#define PIN_S0 GPIO_Pin_0
#define PIN_S1 GPIO_Pin_1
#define PIN_S2 GPIO_Pin_2


/* 
  BLE application advertising packet (max 31 B)
  Each entry is in format:
    [len of next 2 fields in bytes], [AD type (1 B)], [entry value (len-1) B]
*/
const uint8_t device_adv[] = {
  2,  AD_TYPE_TX_POWER_LEVEL, 
      0x00 /* 0 dBm */,
  
  12, AD_TYPE_COMPLETE_LOCAL_NAME, 
      'S','m','a','r','t',' ','G','l','o','v','e',
  
  13, AD_TYPE_MANUFACTURER_SPECIFIC_DATA, 
      0x01, /*SKD version */
      0x04, /* 0x04: BlueNRG1-1/2 eval kits */
      0x00,
      0xD4, /* ACC+Gyro 0xC0 | 0x04 Temp | 0x10 Pressure*/
      0x00, /*  */
      0x00, /*  */
      0x00, /* BLE MAC start */
      0x00,
      0x00,
      0x00,
      0x00,
      0x00 /* BLE MAC stop */
};


/*
  BLE application initialization structure
  Contains all information needed for GAP and GATT setup
*/
static ble_app_t app =
{
  .device_adv = (uint8_t*) device_adv,
  .device_adv_len = sizeof(device_adv),
  .device_addr = {0x12, 0x34, 0x00, 0xE1, 0x80, 0x02},
  .hal_config_data = {
    .Offset = CONFIG_DATA_PUBADDR_OFFSET,
    .Length = CONFIG_DATA_PUBADDR_LEN
  },
  .hal_tx_power_level = {
    .En_High_Power = 1,
    .PA_Power = 4
  },
  .gap = {
    .Role = GAP_PERIPHERAL_ROLE,
    .privacy_enabled = GAP_PRIVACY_DISABLED,
    .Bonding_Mode = BONDING,
    .MITM_Mode = MITM_PROTECTION_REQUIRED,
    .SC_Support = SC_IS_NOT_SUPPORTED,
    .KeyPress_Notification_Support = KEYPRESS_IS_NOT_SUPPORTED,
    .Min_Encryption_Key_Size = 7,
    .Max_Encryption_Key_Size = 16,
    .Use_Fixed_Pin = USE_FIXED_PIN_FOR_PAIRING,
    .Fixed_Pin = 123456,
    .Identity_Address_Type = GAP_ID_PUBLIC_ADDRESS
  },
  .gatt_services = {
    [0] = {
      .uuid.Service_UUID_128 = {0x00,0x00,0x00,0x00,0x00,0x01,0x11,0xe1,0x9a,0xb4,0x00,0x02,0xa5,0xd5,0xc5,0x1b},
      .Service_UUID_Type = UUID_TYPE_128,
      .Service_Type = PRIMARY_SERVICE,
      .Max_Attribute_Records = 1+3*4,
      .gatt_characteristics = {
        [0] = {
          .Char_UUID_Type = UUID_TYPE_128,
          .uuid.Char_UUID_128 = {0x00,0x00,0x00,0x00,0x00,0x01,0x11,0xe1,0xac,0x36,0x00,0x02,0xa5,0xd5,0xc5,0x1b},
          .Char_Value_Length = MEASURED_DATA_MAX_SIZE,
          .Char_Properties = CHAR_PROP_NOTIFY,// | CHAR_PROP_READ,
          .Security_Permissions = ATTR_PERMISSION_NONE,
          .GATT_Evt_Mask = GATT_DONT_NOTIFY_EVENTS,
          .Enc_Key_Size = 16,
          .Is_Variable = CHAR_VALUE_SIZE_FIXED
        },
        [1] = {
          .Char_UUID_Type = UUID_TYPE_128,
          .uuid.Char_UUID_128 = {0x00,0x00,0x00,0x00,0x00,0x01,0x11,0xe1,0xbc,0x56,0x00,0x02,0xa5,0xd5,0xc5,0x1b},
          .Char_Value_Length = CONF_DATA_MAX_SIZE,
          .Char_Properties = CHAR_PROP_NOTIFY | CHAR_PROP_READ,
          .Security_Permissions = ATTR_PERMISSION_NONE,
          .GATT_Evt_Mask = GATT_NOTIFY_READ_REQ_AND_WAIT_FOR_APPL_RESP,
          .Enc_Key_Size = 16,
          .Is_Variable = CHAR_VALUE_SIZE_FIXED
        }
      },
      .gatt_characteristics_num = 2
    }
  },
  .gatt_services_num = 1
};


/* List of all connected sensors */
extern fn_pointers_t fn_pointers_lsm6dsl, fn_pointers_lis2mdl, fn_pointers_lps22hb;

static sensor_t ALL_SENSORS[SENSORS_NUM] = {
  // Sensor #00, SDA1, LSM6DSL, address LOW,  thumb,          proximal phalanx
  { SDA1, LSM6DSL_ACC_GYRO_I2C_ADDRESS_LOW, (fn_pointers_t*) &fn_pointers_lsm6dsl },
  
  // Sensor #01, SDA1, LSM6DSL, address HIGH, thumb,          distal phalanx
  { SDA1, LSM6DSL_ACC_GYRO_I2C_ADDRESS_HIGH, (fn_pointers_t*) &fn_pointers_lsm6dsl },
  
  // Sensor #02, SDA2, LSM6DSL, address LOW,  index finger,   intermediate phalanx
  { SDA2, LSM6DSL_ACC_GYRO_I2C_ADDRESS_LOW, (fn_pointers_t*) &fn_pointers_lsm6dsl },
  
  // Sensor #03, SDA2, LSM6DSL, address HIGH, index finger,   distal phalanx
  { SDA2, LSM6DSL_ACC_GYRO_I2C_ADDRESS_HIGH, (fn_pointers_t*) &fn_pointers_lsm6dsl },
  
  // Sensor #04, SDA3, LSM6DSL, address HIGH, index finger,   proximal phalanx
  { SDA3, LSM6DSL_ACC_GYRO_I2C_ADDRESS_HIGH, (fn_pointers_t*) &fn_pointers_lsm6dsl },
  
  // Sensor #05, SDA3, LSM6DSL, address LOW,  middle finger,  proximal phalanx
  { SDA3, LSM6DSL_ACC_GYRO_I2C_ADDRESS_LOW, (fn_pointers_t*) &fn_pointers_lsm6dsl },
  
  // Sensor #06, SDA4, LSM6DSL, address LOW,  middle finger,  intermediate phalanx
  { SDA4, LSM6DSL_ACC_GYRO_I2C_ADDRESS_LOW, (fn_pointers_t*) &fn_pointers_lsm6dsl },
  
  // Sensor #07, SDA4, LSM6DSL, address HIGH, middle finger,  distal phalanx
  { SDA4, LSM6DSL_ACC_GYRO_I2C_ADDRESS_HIGH, (fn_pointers_t*) &fn_pointers_lsm6dsl },
  
  // Sensor #08, SDA5, LSM6DSL, address LOW,  ring finger,    intermediate phalanx
  { SDA5, LSM6DSL_ACC_GYRO_I2C_ADDRESS_LOW, (fn_pointers_t*) &fn_pointers_lsm6dsl },
  
  // Sensor #09, SDA5, LSM6DSL, address HIGH, ring finger,    distal phalanx
  { SDA5, LSM6DSL_ACC_GYRO_I2C_ADDRESS_HIGH, (fn_pointers_t*) &fn_pointers_lsm6dsl },
  
  // Sensor #10, SDA6, LSM6DSL, address HIGH, ring finger,    proximal phalanx
  { SDA6, LSM6DSL_ACC_GYRO_I2C_ADDRESS_HIGH, (fn_pointers_t*) &fn_pointers_lsm6dsl },
  
  // Sensor #11, SDA6, LSM6DSL, address LOW,  little finger,  proximal phalanx
  { SDA6, LSM6DSL_ACC_GYRO_I2C_ADDRESS_LOW, (fn_pointers_t*) &fn_pointers_lsm6dsl },
  
  // Sensor #12, SDA7, LSM6DSL, address LOW,  little finger,  intermediate phalanx
  { SDA7, LSM6DSL_ACC_GYRO_I2C_ADDRESS_LOW, (fn_pointers_t*) &fn_pointers_lsm6dsl },
  
  // Sensor #13, SDA7, LSM6DSL, address HIGH, little finger,  distal phalanx
  { SDA7, LSM6DSL_ACC_GYRO_I2C_ADDRESS_HIGH, (fn_pointers_t*) &fn_pointers_lsm6dsl },
  
  // Sensor #14, SDA8, LSM6DSL, address HIGH, hand
  { SDA8, LSM6DSL_ACC_GYRO_I2C_ADDRESS_HIGH, (fn_pointers_t*) &fn_pointers_lsm6dsl },
  
  // Sensor #15, SDA8, LPS22HB, address HIGH, hand
  { SDA8, LPS22HB_ADDRESS_HIGH, (fn_pointers_t*) &fn_pointers_lps22hb },
  
  // Sensor #16, SDA8, LIS2MDL, address def., hand
  { SDA8, LIS2MDLSensor_I2C_ADD, (fn_pointers_t*) &fn_pointers_lis2mdl },
};

/* Arrays containing data to send */
uint8_t measured_data[MEASURED_DATA_MAX_SIZE] = {0};
uint8_t conf_data[CONF_DATA_MAX_SIZE] = {0};

adc_measurement_t adc_measurement = { .f = 0.0f };

volatile uint8_t sensors_initialized = 0;

/* Init all sensors */
uint8_t sensors_all_init(void)
{
  for (uint8_t i = 0; i < SENSORS_NUM; i++) {
    if(sensor_init(&ALL_SENSORS[i])) {
      printf("Error when initialising sensor #%02d!\r\n", i);
      return 1;
    }
  }
  return 0;
}

/* Gather data from all sensors + time + ADC */
void sensors_gather_data(void)
{
  uint8_t data_pos = 0;
  
  /* Add time to data packet */
  *((uint32_t*) &measured_data[data_pos]) = get_time_ms();
  data_pos += 4;
  
  /* Add battery voltage to data packet */
  measured_data[data_pos++] = adc_measurement.u8[0];
  measured_data[data_pos++] = adc_measurement.u8[1];
  measured_data[data_pos++] = adc_measurement.u8[2];
  measured_data[data_pos++] = adc_measurement.u8[3];
  
  /* Add sensors measurements to data packet */
  int8_t bytesRead = 0;
  for(uint8_t i = 0; i < SENSORS_NUM; i++) {
    //printf("Get sensor #%02d data to data pos %d / %d ... ", i, data_pos, MEASURED_DATA_MAX_SIZE);
    if((bytesRead = sensor_read_data(&ALL_SENSORS[i], &measured_data[data_pos])) <= 0) {
      printf("Failed to read sensor #%02d data to data pos %d / %d ... ", i, data_pos, MEASURED_DATA_MAX_SIZE);
    } else {
      //printf("success (read %dB)!\r\n", bytesRead);
      data_pos += bytesRead;
    }
  }
  
  /*int16_t i1 = *((int16_t*)&measured_data[8]);
  int16_t i2 = *((int16_t*)&measured_data[10]);
  int16_t i3 = *((int16_t*)&measured_data[12]);
  printf("Sensor #00 measurement: time: %u ms; A: [%d %d %d]\r\n", *((uint32_t*) &measured_data[0]), i1, i2, i3);*/
  
  /* Check if all bytes of packet were written */
  //if (data_pos != MEASURED_DATA_MAX_SIZE) {
    //printf("Weird, the data packet is not complete!\r\n");
  //}
  
  //printf("Gathered %dB\r\n", data_pos);
}

/* Update data packet containing necessary configurations of sensors. */
void update_ble_data_conf(void)
{
  uint8_t data_pos = 0;
  int8_t bytesRead = 0;
  for(uint8_t i = 0; i < SENSORS_NUM; i++) {
    conf_data[data_pos++] = i;
    if((bytesRead = sensor_read_conf(&ALL_SENSORS[i], &conf_data[data_pos])) <= 0) {
      data_pos--;
    } else {
      data_pos += bytesRead;
    }
  }
  
  ble_app_update_char_value(app.gatt_services[0].handle, app.gatt_services[0].gatt_characteristics[1].handle, (uint8_t*) &conf_data, data_pos);
}

void update_ble_data(void)
{
  uint8_t len = app.gatt_services[0].gatt_characteristics[0].Char_Value_Length;
  ble_app_update_char_value(app.gatt_services[0].handle, app.gatt_services[0].gatt_characteristics[0].handle, (uint8_t*) &measured_data, len);
}

void gpio_setup(void)
{
  /* Periph clock enable */
  SysCtrl_PeripheralClockCmd(CLOCK_PERIPH_GPIO, ENABLE);
	
	// UART pins
  GPIO_InitUartTxPin8(); // TXD at DIO8
  GPIO_InitUartRxPin11(); // RXD at DIO11
	
	// I2C2 pins
	GPIO_InitI2c2ClkPin4(); // SCL at DIO4
	GPIO_InitI2c2DataPin5(); // SDA at DIO5
  
  // LED pins
  GPIO_InitOutputPinx(PIN_LED3); // LED3 at DIO3
  GPIO_InitOutputPinx(PIN_LED4); // LED4 at DIO6
  GPIO_InitOutputPinx(PIN_LED5); // LED5 at DIO12
  GPIO_ResetBits(PIN_LED3 | PIN_LED4 | PIN_LED5);
  
  // Select pins for MUX
  GPIO_InitOutputPinx(PIN_S0); // S0 at DIO0
  GPIO_InitOutputPinx(PIN_S1); // S1 at DIO1
  GPIO_InitOutputPinx(PIN_S2); // S2 at DIO2
}

void systick_ms_callback(uint32_t ms)
{
  if (ms % 1000 == 0) {
    adc_read(&adc_measurement);
    adc_measurement.f *= (43.0f/33.0f);
  }
}

int main(void)
{  
  uint32_t last_update_ms = 0, time = 0;
  
  SystemInit();
	gpio_setup();
  
  GPIO_SetBits(PIN_LED3);
  
	uart_init();
	systick_init();
	mft_init();
	adc_init();
  i2c_init();
  
  printf("\r\nBlueNRG-2 BLE Application (version: %s)\r\n", BLE_APP_VERSION_STRING);
  uint8_t ret;
  
  /* Initialize all sensors */
  if(sensors_all_init()) {
    printf("Failed to initialize all sensors!\r\n");
    goto fault_state;
  } else {
    printf("All sensors initialized successfully.\r\n");
  }
  
	/* BLE Device Init */
  ret = ble_app_init(&app);
  if (ret != BLE_STATUS_SUCCESS) {
    printf("Error in ble_app_init() 0x%02x\r\n", ret);
    goto fault_state;
  } else {    
    printf("BLE app initialized successfully.\r\n");
  }
  
  /* Put device in general discoverable mode */
  ble_app_set_connectable(&app);
  
  update_ble_data_conf();
	
  GPIO_ResetBits(PIN_LED3);
  
  sensors_initialized = 1;
  
  while(1) {	
    /* Update the data */
    time = get_time_ms();
    if (time - last_update_ms > (DATA_REFRESH_PERIOD_MS - 1)) {
      sensors_gather_data();
      update_ble_data();
      last_update_ms = time;
    }
    
    /* BLE stack tick */
    ble_stack_tick();
    
    /* Application Tick */
    ble_app_tick();
    
    /* BLE sleep for power saving */
    ble_sleep();
  }
  
  /* Fault state - red LED blinking quickly */
fault_state:
  while(1) {
    GPIO_ToggleBits(PIN_LED4);
    delay_ms(50UL);
  }
}

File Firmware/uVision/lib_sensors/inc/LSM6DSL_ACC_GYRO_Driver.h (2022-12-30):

/**
 ******************************************************************************
 * @file    LSM6DSL_ACC_GYRO_driver.h
 * @author  MEMS Application Team
 * @version V1.5
 * @date    17-May-2016
 * @brief   LSM6DSL header driver file
 ******************************************************************************
 * @attention
 *
 * <h2><center>&copy; COPYRIGHT(c) 2017 STMicroelectronics</center></h2>
 *
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
 ******************************************************************************
 */

/* Define to prevent recursive inclusion -------------------------------------*/
#ifndef __LSM6DSL_ACC_GYRO_DRIVER__H
#define __LSM6DSL_ACC_GYRO_DRIVER__H

/* Includes ------------------------------------------------------------------*/
#include <stdint.h>

/* Exported types ------------------------------------------------------------*/

#ifdef __cplusplus
extern "C" {
#endif


/* Exported common structure --------------------------------------------------------*/

#ifndef __SHARED__TYPES
#define __SHARED__TYPES

typedef union{
	int16_t i16bit[3];
	uint8_t u8bit[6];
} Type3Axis16bit_U;

typedef union{
	int16_t i16bit;
	uint8_t u8bit[2];
} Type1Axis16bit_U;

typedef union{
	int32_t i32bit;
	uint8_t u8bit[4];
} Type1Axis32bit_U;

typedef enum {
  MEMS_SUCCESS				=		0x01,
  MEMS_ERROR				=		0x00
} mems_status_t;

#endif /*__SHARED__TYPES*/

/* Exported macro ------------------------------------------------------------*/

/* Exported constants --------------------------------------------------------*/

/************** I2C Address *****************/

#define LSM6DSL_ACC_GYRO_I2C_ADDRESS_LOW   0xD4  // SAD[0] = 0
#define LSM6DSL_ACC_GYRO_I2C_ADDRESS_HIGH  0xD6  // SAD[0] = 1

/************** Who am I  *******************/

#define LSM6DSL_ACC_GYRO_WHO_AM_I         0x6A

/************** Device Register  *******************/

#define LSM6DSL_ACC_GYRO_FUNC_CFG_ACCESS  	0X01

#define LSM6DSL_ACC_GYRO_SENSOR_SYNC_TIME  	0X04
#define LSM6DSL_ACC_GYRO_SENSOR_RES_RATIO  	0X05

#define LSM6DSL_ACC_GYRO_FIFO_CTRL1  	0X06
#define LSM6DSL_ACC_GYRO_FIFO_CTRL2  	0X07
#define LSM6DSL_ACC_GYRO_FIFO_CTRL3  	0X08
#define LSM6DSL_ACC_GYRO_FIFO_CTRL4  	0X09
#define LSM6DSL_ACC_GYRO_FIFO_CTRL5  	0X0A

#define LSM6DSL_ACC_GYRO_DRDY_PULSE_CFG_G  	0X0B
#define LSM6DSL_ACC_GYRO_INT1_CTRL  	0X0D
#define LSM6DSL_ACC_GYRO_INT2_CTRL  	0X0E
#define LSM6DSL_ACC_GYRO_WHO_AM_I_REG  	0X0F
#define LSM6DSL_ACC_GYRO_CTRL1_XL  	0X10
#define LSM6DSL_ACC_GYRO_CTRL2_G  	0X11
#define LSM6DSL_ACC_GYRO_CTRL3_C  	0X12
#define LSM6DSL_ACC_GYRO_CTRL4_C  	0X13
#define LSM6DSL_ACC_GYRO_CTRL5_C  	0X14
#define LSM6DSL_ACC_GYRO_CTRL6_G  	0X15
#define LSM6DSL_ACC_GYRO_CTRL7_G  	0X16
#define LSM6DSL_ACC_GYRO_CTRL8_XL  	0X17
#define LSM6DSL_ACC_GYRO_CTRL9_XL  	0X18
#define LSM6DSL_ACC_GYRO_CTRL10_C  	0X19

#define LSM6DSL_ACC_GYRO_MASTER_CONFIG  	0X1A
#define LSM6DSL_ACC_GYRO_WAKE_UP_SRC  	0X1B
#define LSM6DSL_ACC_GYRO_TAP_SRC  	0X1C
#define LSM6DSL_ACC_GYRO_D6D_SRC  	0X1D
#define LSM6DSL_ACC_GYRO_STATUS_REG  	0X1E

#define LSM6DSL_ACC_GYRO_OUT_TEMP_L  	0X20
#define LSM6DSL_ACC_GYRO_OUT_TEMP_H  	0X21
#define LSM6DSL_ACC_GYRO_OUTX_L_G  	0X22
#define LSM6DSL_ACC_GYRO_OUTX_H_G  	0X23
#define LSM6DSL_ACC_GYRO_OUTY_L_G  	0X24
#define LSM6DSL_ACC_GYRO_OUTY_H_G  	0X25
#define LSM6DSL_ACC_GYRO_OUTZ_L_G  	0X26
#define LSM6DSL_ACC_GYRO_OUTZ_H_G  	0X27
#define LSM6DSL_ACC_GYRO_OUTX_L_XL  	0X28
#define LSM6DSL_ACC_GYRO_OUTX_H_XL  	0X29
#define LSM6DSL_ACC_GYRO_OUTY_L_XL  	0X2A
#define LSM6DSL_ACC_GYRO_OUTY_H_XL  	0X2B
#define LSM6DSL_ACC_GYRO_OUTZ_L_XL  	0X2C
#define LSM6DSL_ACC_GYRO_OUTZ_H_XL  	0X2D
#define LSM6DSL_ACC_GYRO_SENSORHUB1_REG  	0X2E
#define LSM6DSL_ACC_GYRO_SENSORHUB2_REG  	0X2F
#define LSM6DSL_ACC_GYRO_SENSORHUB3_REG  	0X30
#define LSM6DSL_ACC_GYRO_SENSORHUB4_REG  	0X31
#define LSM6DSL_ACC_GYRO_SENSORHUB5_REG  	0X32
#define LSM6DSL_ACC_GYRO_SENSORHUB6_REG  	0X33
#define LSM6DSL_ACC_GYRO_SENSORHUB7_REG  	0X34
#define LSM6DSL_ACC_GYRO_SENSORHUB8_REG  	0X35
#define LSM6DSL_ACC_GYRO_SENSORHUB9_REG  	0X36
#define LSM6DSL_ACC_GYRO_SENSORHUB10_REG  	0X37
#define LSM6DSL_ACC_GYRO_SENSORHUB11_REG  	0X38
#define LSM6DSL_ACC_GYRO_SENSORHUB12_REG  	0X39
#define LSM6DSL_ACC_GYRO_FIFO_STATUS1  	0X3A
#define LSM6DSL_ACC_GYRO_FIFO_STATUS2  	0X3B
#define LSM6DSL_ACC_GYRO_FIFO_STATUS3  	0X3C
#define LSM6DSL_ACC_GYRO_FIFO_STATUS4  	0X3D
#define LSM6DSL_ACC_GYRO_FIFO_DATA_OUT_L  	0X3E
#define LSM6DSL_ACC_GYRO_FIFO_DATA_OUT_H  	0X3F
#define LSM6DSL_ACC_GYRO_TIMESTAMP0_REG  	0X40
#define LSM6DSL_ACC_GYRO_TIMESTAMP1_REG  	0X41
#define LSM6DSL_ACC_GYRO_TIMESTAMP2_REG  	0X42

#define LSM6DSL_ACC_GYRO_TIMESTAMP_L  	0X49
#define LSM6DSL_ACC_GYRO_TIMESTAMP_H  	0X4A

#define LSM6DSL_ACC_GYRO_STEP_COUNTER_L  	0X4B
#define LSM6DSL_ACC_GYRO_STEP_COUNTER_H  	0X4C

#define LSM6DSL_ACC_GYRO_SENSORHUB13_REG  	0X4D
#define LSM6DSL_ACC_GYRO_SENSORHUB14_REG  	0X4E
#define LSM6DSL_ACC_GYRO_SENSORHUB15_REG  	0X4F
#define LSM6DSL_ACC_GYRO_SENSORHUB16_REG  	0X50
#define LSM6DSL_ACC_GYRO_SENSORHUB17_REG  	0X51
#define LSM6DSL_ACC_GYRO_SENSORHUB18_REG  	0X52

#define LSM6DSL_ACC_GYRO_FUNC_SRC  	0X53
#define LSM6DSL_ACC_GYRO_TAP_CFG1  	0X58
#define LSM6DSL_ACC_GYRO_TAP_THS_6D  	0X59
#define LSM6DSL_ACC_GYRO_INT_DUR2  	0X5A
#define LSM6DSL_ACC_GYRO_WAKE_UP_THS  	0X5B
#define LSM6DSL_ACC_GYRO_WAKE_UP_DUR  	0X5C
#define LSM6DSL_ACC_GYRO_FREE_FALL  	0X5D
#define LSM6DSL_ACC_GYRO_MD1_CFG  	0X5E
#define LSM6DSL_ACC_GYRO_MD2_CFG  	0X5F

#define LSM6DSL_ACC_GYRO_OUT_MAG_RAW_X_L  	0X66
#define LSM6DSL_ACC_GYRO_OUT_MAG_RAW_X_H  	0X67
#define LSM6DSL_ACC_GYRO_OUT_MAG_RAW_Y_L  	0X68
#define LSM6DSL_ACC_GYRO_OUT_MAG_RAW_Y_H  	0X69
#define LSM6DSL_ACC_GYRO_OUT_MAG_RAW_Z_L  	0X6A
#define LSM6DSL_ACC_GYRO_OUT_MAG_RAW_Z_H  	0X6B

#define LSM6DSL_ACC_GYRO_X_OFS_USR  	0X73
#define LSM6DSL_ACC_GYRO_Y_OFS_USR  	0X74
#define LSM6DSL_ACC_GYRO_Z_OFS_USR  	0X75

/************** Embedded functions register mapping  *******************/
#define LSM6DSL_ACC_GYRO_SLV0_ADD                     0x02
#define LSM6DSL_ACC_GYRO_SLV0_SUBADD                  0x03
#define LSM6DSL_ACC_GYRO_SLAVE0_CONFIG                0x04
#define LSM6DSL_ACC_GYRO_SLV1_ADD                     0x05
#define LSM6DSL_ACC_GYRO_SLV1_SUBADD                  0x06
#define LSM6DSL_ACC_GYRO_SLAVE1_CONFIG                0x07
#define LSM6DSL_ACC_GYRO_SLV2_ADD                     0x08
#define LSM6DSL_ACC_GYRO_SLV2_SUBADD                  0x09
#define LSM6DSL_ACC_GYRO_SLAVE2_CONFIG                0x0A
#define LSM6DSL_ACC_GYRO_SLV3_ADD                     0x0B
#define LSM6DSL_ACC_GYRO_SLV3_SUBADD                  0x0C
#define LSM6DSL_ACC_GYRO_SLAVE3_CONFIG                0x0D
#define LSM6DSL_ACC_GYRO_DATAWRITE_SRC_MODE_SUB_SLV0  0x0E
#define LSM6DSL_ACC_GYRO_CONFIG_PEDO_THS_MIN          0x0F

#define LSM6DSL_ACC_GYRO_SM_STEP_THS                  0x13
#define LSM6DSL_ACC_GYRO_PEDO_DEB_REG                0x14
#define LSM6DSL_ACC_GYRO_STEP_COUNT_DELTA            0x15
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

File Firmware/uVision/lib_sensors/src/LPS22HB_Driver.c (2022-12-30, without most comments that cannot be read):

/**
 *******************************************************************************
 * @file    LPS22HB_Driver.c
 * @author  HESA Application Team
 * @version V1.1
 * @date    10-August-2016
 * @brief   LPS22HB driver file
 *******************************************************************************
 * @attention
 *
 * <h2><center>&copy; COPYRIGHT(c) 2017 STMicroelectronics</center></h2>
 *
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
 ******************************************************************************
 */

/* Includes ------------------------------------------------------------------*/
#include "../inc/LPS22HB_Driver.h"


/** @addtogroup Environmental_Sensor
* @{
*/

/** @defgroup LPS22HB_DRIVER
* @brief LPS22HB DRIVER
* @{
*/

/** @defgroup LPS22HB_Imported_Function_Prototypes
* @{
*/
extern int i2c_write(uint8_t reg, uint8_t* data, uint8_t len);
extern int i2c_read(uint8_t reg, uint8_t* data, uint8_t len);

/**
* @}
*/

/** @defgroup LPS22HB_Private_Function_Prototypes
* @{
*/

/**
* @}
*/

/** @defgroup LPS22HB_Private_Functions
* @{
*/

/**
* @}
*/

/** @defgroup LPS22HB_Public_Functions
* @{
*/

/*******************************************************************************
* Function Name   : LPS22HB_ReadReg
* Description   : Generic Reading function. It must be fullfilled with either
*         : I2C or SPI reading functions
* Input       : Register Address
* Output      : Data Read
* Return      : None
*******************************************************************************/
LPS22HB_Error_et LPS22HB_ReadReg( uint8_t RegAddr, uint16_t NumByteToRead, uint8_t *Data )
{
  if (i2c_read(RegAddr, Data, NumByteToRead))
  {
    return LPS22HB_ERROR;
  }
  else
  {
    return LPS22HB_OK;
  }
}

/*******************************************************************************
* Function Name   : LPS22HB_WriteReg
* Description   : Generic Writing function. It must be fullfilled with either
*         : I2C or SPI writing function
* Input       : Register Address, Data to be written
* Output      : None
* Return      : None
*******************************************************************************/
LPS22HB_Error_et LPS22HB_WriteReg( uint8_t RegAddr, uint16_t NumByteToWrite, uint8_t *Data )
{
  if (i2c_write(RegAddr, Data, NumByteToWrite))
  {
    return LPS22HB_ERROR;
  }
  else
  {
    return LPS22HB_OK;
  }
}

/**
* @brief  Read identification code by WHO_AM_I register
* @param  * Device .
* @param  Buffer to empty by Device identification Value.
* @retval Error Code [LPS22HB_ERROR, LPS22HB_OK]
*/
LPS22HB_Error_et LPS22HB_Get_DeviceID(uint8_t* deviceid)
{
  if(LPS22HB_ReadReg(LPS22HB_WHO_AM_I_REG, 1, deviceid))
    return LPS22HB_ERROR;

  return LPS22HB_OK;
}


/**
* @brief  Get the LPS22HB driver version.
* @param  None
* @retval Error Code [LPS22HB_ERROR, LPS22HB_OK]
*/
LPS22HB_Error_et LPS22HB_Get_DriverVersion(LPS22HB_DriverVersion_st *Version)
{
  Version->Major = LPS22HB_DriverVersion_Major;
  Version->Minor = LPS22HB_DriverVersion_Minor;
  Version->Point = LPS22HB_DriverVersion_Point;

  return LPS22HB_OK;
}


/**
* @brief  Set LPS22HB Low Power or Low Noise Mode Configuration
* @param  * Device .
* @param  LPS22HB_LowNoise or LPS22HB_LowPower mode
* @retval Error Code [LPS22HB_ERROR, LPS22HB_OK]
*/
LPS22HB_Error_et LPS22HB_Set_PowerMode(LPS22HB_PowerMode_et mode)
{
  uint8_t tmp;

  LPS22HB_assert_param(IS_LPS22HB_PowerMode(mode));

  if(LPS22HB_ReadReg(LPS22HB_RES_CONF_REG, 1, &tmp))
    return LPS22HB_ERROR;

  tmp &= ~LPS22HB_LCEN_MASK;
  tmp |= (uint8_t)mode;

  if(LPS22HB_WriteReg(LPS22HB_RES_CONF_REG, 1, &tmp))
    return LPS22HB_ERROR;

  return LPS22HB_OK;
}

/**
* @brief  Get LPS22HB Power Mode
* @param  * Device .
* @param   Buffer to empty with Mode: Low Noise or Low Current
* @retval Error Code [LPS22HB_ERROR, LPS22HB_OK]
*/
LPS22HB_Error_et LPS22HB_Get_PowerMode(LPS22HB_PowerMode_et* mode)
{
  uint8_t tmp;

  if(LPS22HB_ReadReg(LPS22HB_RES_CONF_REG, 1, &tmp))
    return LPS22HB_ERROR;

  *mode = (LPS22HB_PowerMode_et)(tmp & LPS22HB_LCEN_MASK);

  return LPS22HB_OK;
}
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

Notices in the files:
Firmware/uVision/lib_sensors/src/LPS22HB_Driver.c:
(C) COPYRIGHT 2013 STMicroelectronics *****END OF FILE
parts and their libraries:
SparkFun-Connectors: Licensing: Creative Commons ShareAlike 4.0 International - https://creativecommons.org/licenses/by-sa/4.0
